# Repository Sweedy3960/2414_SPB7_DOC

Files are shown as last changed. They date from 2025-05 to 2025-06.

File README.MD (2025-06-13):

# 2414_SPB7 – Testeur de Sprinkler

Ce projet implémente un système embarqué pour le test et la gestion de modules Sprinkler, basé sur une architecture modulaire et des tâches gérées par machine à états (FSM), pour microcontrôleur PIC32.

## Sommaire

- [Présentation](#présentation)
- [Fonctionnalités principales](#fonctionnalités-principales)
- [Organisation du projet](#organisation-du-projet)
- [Tableau des fichiers principaux](#tableau-des-fichiers-principaux)
- [Environnement de développement](#environnement-de-développement)
- [Compilation](#compilation)
- [Utilisation](#utilisation)
- [Suivi des tâches](#suivi-des-tâches)
- [Documentation](#documentation)
- [Ressources](#ressources)
- [Notes](#notes)

## Présentation

Ce dépôt contient le code source, la documentation et la configuration pour le projet de testeur de modules Sprinkler.  
L’architecture est orientée événements et intègre la gestion de multiples périphériques (RTC, Touch, ADC, Display, LED, Relais, Buzzer, Bluetooth, SD Card).

## Fonctionnalités principales

- Portage et test de modules (RTC, Touch, ADC, Display, LED, Relais, Buzzer, BT, SD)
- Gestion des tâches via FSM (Harmony)
- Bus d’événements (publish/subscribe)
- Contrôle dynamique des modules (activation, désactivation, flags)
- Gestion des accès I2C/SPI pour éviter les conflits
- Intégration dans la boucle système `SYS_Tasks()`
- Tests de robustesse (non-blocage, endurance SD, consommation)

## Organisation du projet

```
.
├── README.MD
├── doc/
│   ├── ... (documents techniques, schémas, grilles d’évaluation, etc.)
│   ├── EstimPrice/
│   ├── garbage/
│   ├── others/
│   ├── parts/
│   ├── Project Outputs for .../
│   ├── rendus/
├── hard/
│   ├── ... (fichiers hardware, PCB, STEP, etc.)
├── mec/
│   ├── ... (fichiers mécaniques, STEP, DXF, SLDASM, etc.)
├── soft/
│   ├── Chemin.txt
│   ├── Projet.zip
├── tools/
```

## Tableau des fichiers principaux

| Chemin relatif | Description |
|---|---|
| `README.MD` | Présentation et suivi du projet |
| `doc/` | Documentation, rapports, schémas, grilles |
| `doc/EstimPrice/` | Estimations de prix, images de commandes |
| `doc/garbage/` | Archives, idées, schémas à trier |
| `doc/others/` | Notes techniques, calculs, docs annexes |
| `doc/parts/` | Datasheets, notes d’application |
| `doc/Project Outputs for 2414_SAG/` | Sorties CAO, DRC, EuroCircuits, docs design |
| `doc/Project Outputs for 2414_ScreenHolder/` | Idem pour ScreenHolder |
| `doc/Project Outputs for 2414_TesteurDeSprinkler_SPB7/` | Idem pour TesteurDeSprinkler_SPB7 |
| `doc/Project Outputs for 2414_TesteurDeSprinkler_TouchCapa/`| Idem pour TouchCapa |
| `hard/` | Fichiers hardware, PCB, empreintes, etc. |
| `mec/` | Fichiers mécaniques, STEP, DXF, SLDASM |
| `soft/` | Logiciel embarqué, chemins, archives projet |
| `tools/` | Outils divers liés au projet |

## Environnement de développement

- **IDE recommandé** : MPLAB X IDE (Microchip) ou équivalent compatible Harmony
- **Compilateur** : XC32 v2.5 
- **Plateforme cible** : Microcontrôleur PIC32mx79512fl

## Compilation

1. Cloner le repos en local sur la machine 
2. Décompresser le dossier projet dans " C:\microchip\harmony\v2_06\apps\MINF" 
3. Dans Mplab ouvrir le prrojet souhaiter 
4. Vérifier la configuration du compilateur (XC32).
5. Compiler le projet (`Build Project`).
6. Programmer la cible via l’outil de programmation (PICkit, ICD, etc.).

## Utilisation

- Actuellement en développement pas d'utilisation  "normale", le projet flasher est le "SPSPB7_Assembly" 
- Pour l'instant alimenter le prjet en +3V3 sur les fils qui ressortes du boitier 
- une séquence de bienvenus s'affiche, les actions sur les toucbes capacitives on un effet sur les leds et écrans 

- Le  projet "2414-DES_SP7_TestSprinkler" est l'ancienne version du programme de test, il n'est pas utilisable simplement
- il faut l'utiliser en débug et "activer" les fonctionalité à testet grace à des variables globales
- sur cette ancienne version, les fonctionnalité ont été validée jsuqu'a la carte SD 

L'ordre des fonctionalité implémentée: 
- voir rapport

## Taches à venir

- [ ] Repartir sur un projet MPlab vierge et faire la configuration corectement
- [ ] Finir inpmlémenter appInputs -> refractor sm et reconfigurer ADC pour lecture plus rapide 
- [ ] Ajouter la gestion de la tache et crée les fonction de handling
- [ ] Crée la logique pour reporter les entrée sur les sorties 
- [ ] Ajouter l'app MCP /RTC 
- [ ] Ajouter l'app Bluetooth
- [ ] Ajouter l'app Buzzer

## Documentation

La documentation technique (Doxygen, schémas, diagrammes) est disponible dans le dossier du projet:

2414-DES_SP7_TestSprinkler doc : C:\microchip\harmony\v2_06\apps\MINF\Projet\2414-DES_SP7_TestSprinkler\firmware\src\html\index.html"
SPSPB7_Assembly doc: "C:\microchip\harmony\v2_06\apps\MINF\Projet\SPB7_Assembly\firmware\src\html\index.html"

## Ressources

- [MPLAB X IDE](https://www.microchip.com/en-us/tools-resources/develop/mplab-x-ide)
- [Doxygen](https://www.doxygen.nl/index.html)
- [Documentation Microchip PIC32MM](https://www.microchip.com/wwwproducts/en/PIC32MM0064GPL020)
- [VS Code](https://code.visualstudio.com/)
- [Graphviz](https://graphviz.gitlab.io/)

## Notes

- Pour toute modification, mettre à jour ce README et la checklist.
- Les chemins et fichiers peuvent évoluer selon l’avancement du projet.

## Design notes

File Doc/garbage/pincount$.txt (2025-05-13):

pre: 1in 2 out = 3 GPIO
vane: 1in 2 out = 3
test: 1in 2 out = 3
5in:  5 in 10 out = 15
3 in: 3 Ain 3 out = 6
bt: 1in 1 out = 2
buz: 1 out = 1
alarm 1 out = 1
Esser: 24
relais 5 out  = 5 
screen:8 out = 8 
SD:SPI 5 = 6
usb: 2
capa:

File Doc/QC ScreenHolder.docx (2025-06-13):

Dessiné par | ACL | Date dessin | 2025.01.31
Contrôlé par | VCO | Date contrôle | 2025.03.28
N° document | 2414.0000.vo | Nom du projet | SPB7_ScreenHolder

Dessinateur | Contrôleur | Pas applicable | Contrôle | Critères / Remarques

Schéma électrique (SCH)
☒ | ☒ | ☐ | Cartouche | Cartouche complet avec numérotation des pages
☒ | ☒ | ☐ | Repérage | Lettres repères conforme aux normes CEI 81346
☒ | ☒ | ☐ | Symboles | Symboles conformes aux normes CEI 60617
☒ | ☒ | ☐ | Textes | Tous les textes lisibles avec deux sens de lecture
☒ | ☒ | ☐ | Connexions | Fils verticaux ou horizontaux sur une grille de 2.5 mm
☒ | ☒ | ☐ | Exhaustivité | Toutes les connexions nécessaires sont présentes
☒ | ☒ | ☐ | Compilation | Le projet compile sans erreurs

Tracé du circuit imprimé (PCB)
☒ | ☒ | ☐ | Cartouche | Cartouche complet sans numérotation des pages
☒ | ☒ | ☐ | Sérigraphie | Tous les textes lisibles avec deux sens de lecture
☒ | ☒ | ☐ | Graphique / mécanique | Retirer la référence de la sérigraphie
☒ | ☒ | ☐ | Dimensions | Coter le contour mécanique du PCB
☒ | ☒ | ☐ | Découplage | Capacités de découplages au plus près des composants
☒ | ☒ | ☐ | Alimentation | Plans ou topologie en étoile, éviter les boucles, GND et VCCs proches, largeur adaptée
☒ | ☒ | ☐ | Routage | Angles de 45°, largeur appropriées, minimiser les vias, plan de masse sous les composants critiques (ex. quartz)
☒ | ☒ | ☐ | Tables | Table des perçages, numérotation des couches cuivre
☒ | ☒ | ☐ | Règles de conception | Contrôle des règles (DRC) sans erreur

Pochoir (stencil, inclus dans le PCB)
☐ | ☐ | ☒ | Calculs | Calculs des ratios IPC-7525B sur les pastilles critiques, sélection de l’épaisseur du pochoir
☐ | ☐ | ☒ | Réduction | 50 µm ou 10 % ou règle 50/50 pour le fine-pitch
☐ | ☐ | ☒ | Arrondi | Ouvertures arrondies, pas d’angles droits
☐ | ☐ | ☒ | Grandes pastilles | Réduction ou découpage en carrés (50 % surface)

Assemblage (ASY)
☐ | ☐ | ☒ | Cartouche | Cartouche complet avec numérotation des pages
☒ | ☒ | ☐ | Textes | Tous les textes lisibles avec deux sens de lecture
☒ | ☒ | ☐ | Valeurs | La valeur des composants est indiquée sur le dessin

Liste de pièces (BOM)
☒ | ☒ | ☐ | Cartouche | Cartouche complet avec numérotation des pages
☒ | ☒ | ☐ | Contenu | Liste à jour, aux normes ETML, groupée valeur, boîtier

Fichier de placement (PAP)
☐ | ☐ | ☒ | Fichier de placement | Placement à jour, aux normes ETML

Dossier de fabrication (Manufacturing)
☐ | ☐ | ☒ | Dossier Titre_date.zip | Couches format Gerber RS-274X et perçages NC Drill

ETML Liste de contrôle PCB Page 1/2

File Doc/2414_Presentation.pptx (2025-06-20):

## Présentation

Projet : 2414_Testeur de sprinkler

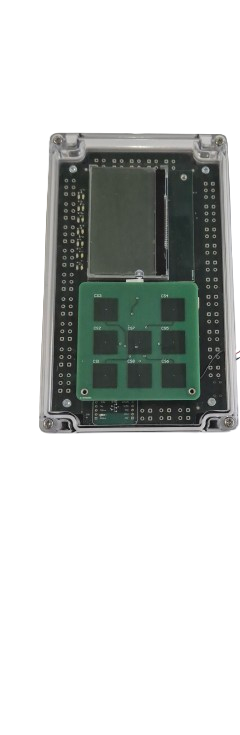
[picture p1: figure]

## Plan de présentation

- 1. Introduction
- 2.Tests et Mesures
- 3. Programmation
- 4. Fait depuis le rendu
- 5. Etat actuel
- 6. Démonstration
- 7. Conclusion

## 1. Introduction

- Contexte du projet:
- Il s’agit de réaliser une évolution d’un boîtier de test pour Sprinkler (détection incendie - DI). Intégration mécanique, densité des composants, fonctionnalités
- I/O extendeur pour Esser 4in/2out
- Le système est censé reporter l’état de certaines entrée sur les sorties en fonction de la configuration initiale affichée l’état et le nom des signaux sur le LCD et utiliser les LEDS pour afficher l’état et faire une sauvegarde

## 2. Test et mesures

- Tests mécaniques et montage du boîtier
- Montage par fonctionnalité progressive
- I/O
- BUS
- Etc

Étapes initiales

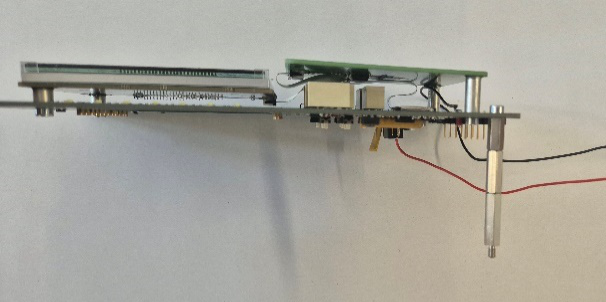
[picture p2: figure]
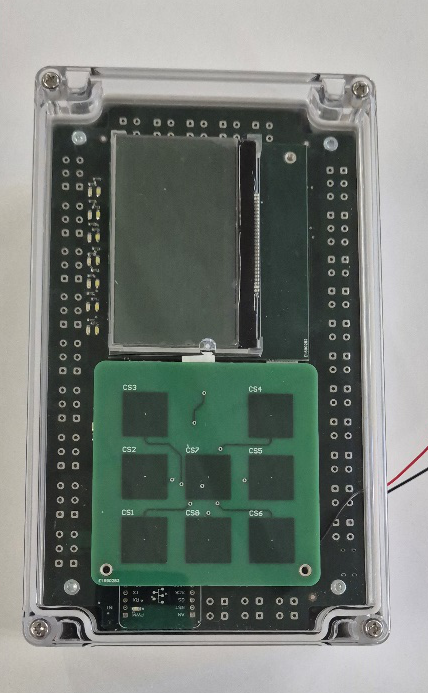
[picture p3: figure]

## 2. Test et mesures - Correction

- Buzzer

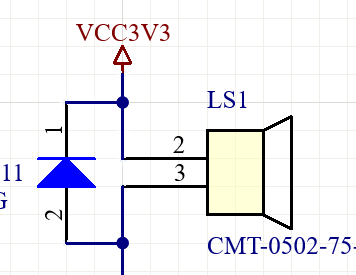
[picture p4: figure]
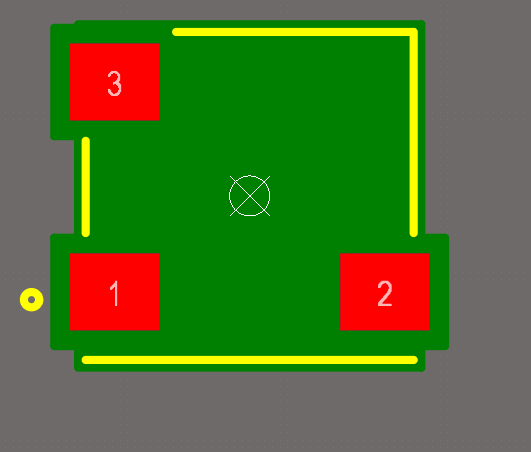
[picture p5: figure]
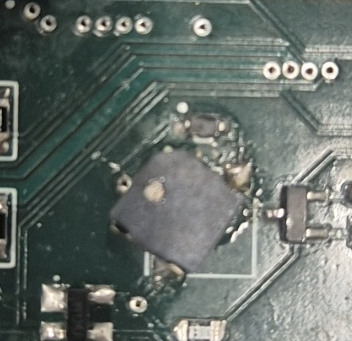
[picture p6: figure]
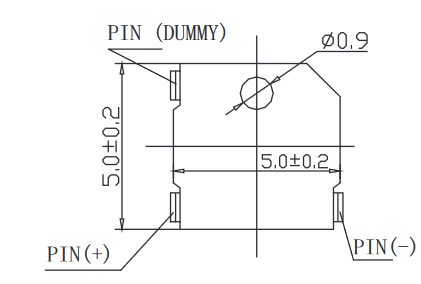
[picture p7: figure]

## 2. Test et mesures - Correction

- Relais

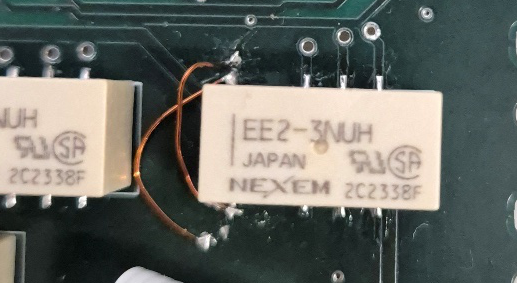
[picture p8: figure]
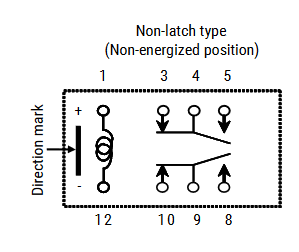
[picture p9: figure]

## 2. Test et mesures - Correction

- Registre à décalage

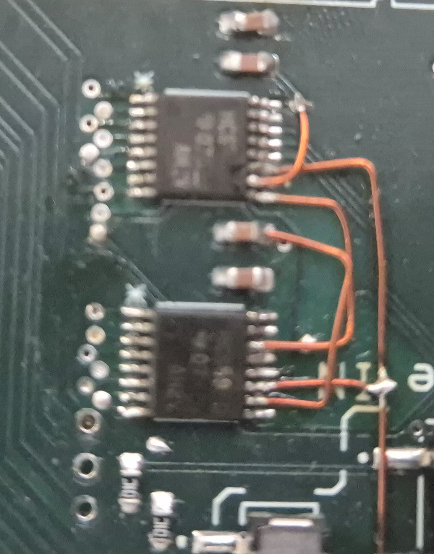
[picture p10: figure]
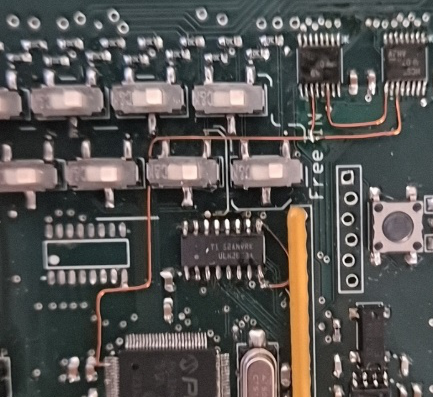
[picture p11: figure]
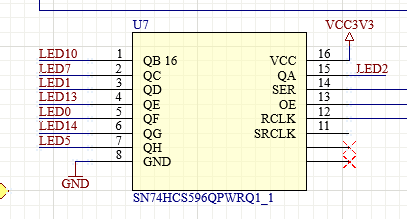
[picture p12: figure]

## 2. Test et mesures - Correction

- Transistor array

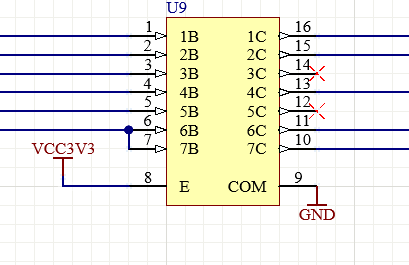
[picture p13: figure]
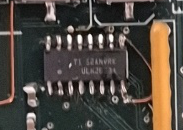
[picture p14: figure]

## 2. Test et mesures - Correction

- SDA/SCL inversés sur TouchCapa

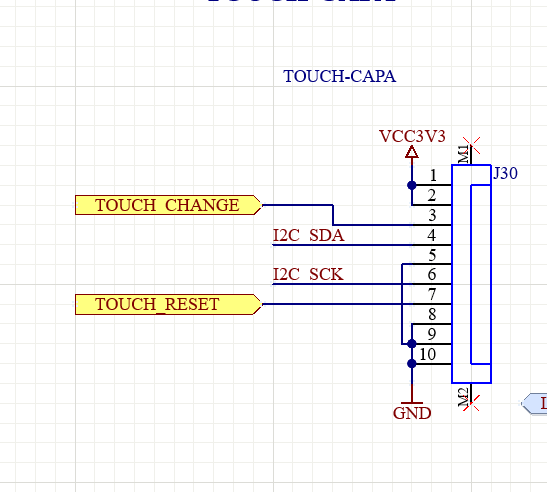
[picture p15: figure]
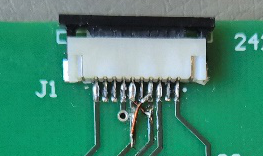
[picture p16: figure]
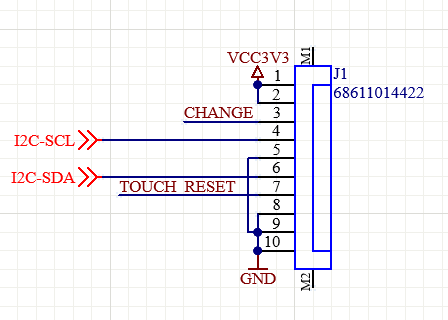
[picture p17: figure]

## 3. Programmation - Fonctionnalités testées

- Entrées digitales et analogiques
- Relais
- RTC
- Touches capacitives
- écran LCD
- Buzzer
- Registre à décalage

## 3. Programmation - Functionalités testées – Problèmes

- Carte SD non détectée (FAT16/FAT32)
- Capacité RTC inefficace à maintenir tension

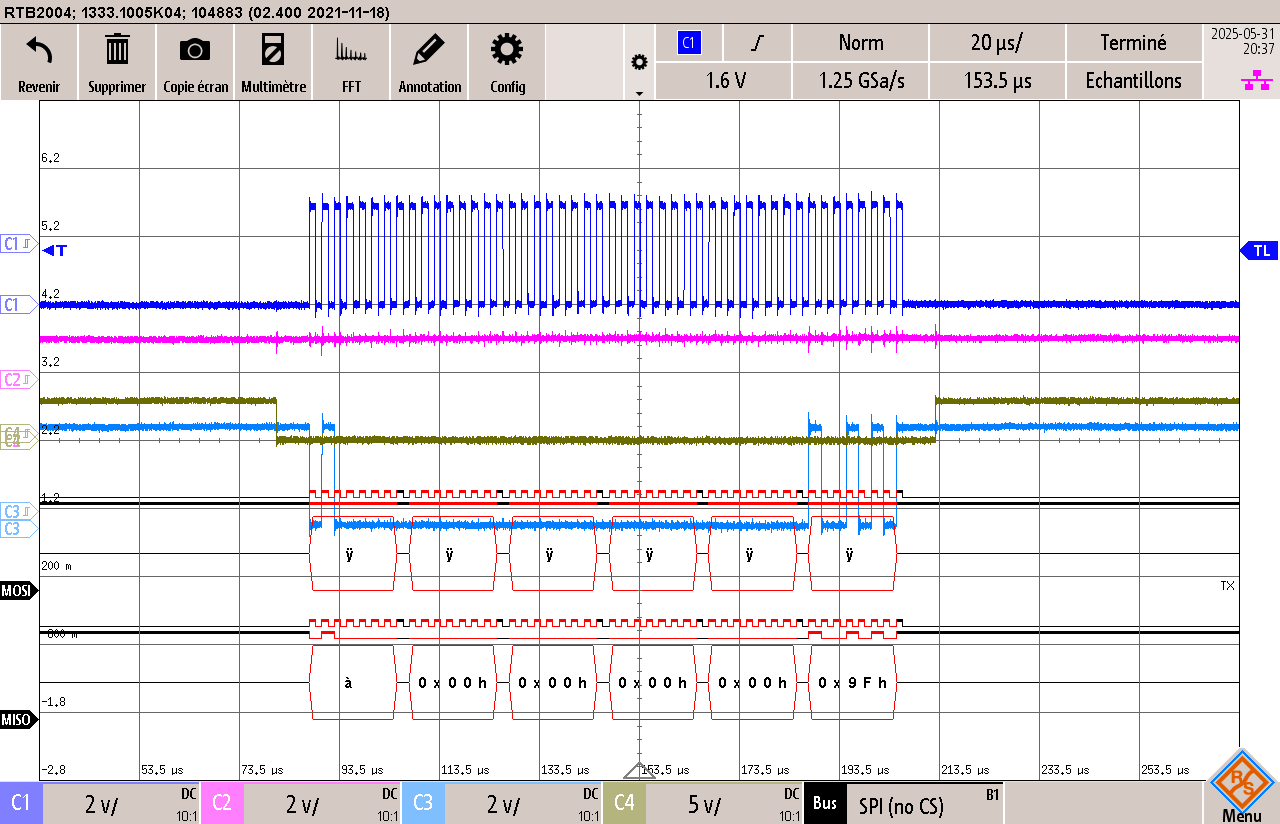
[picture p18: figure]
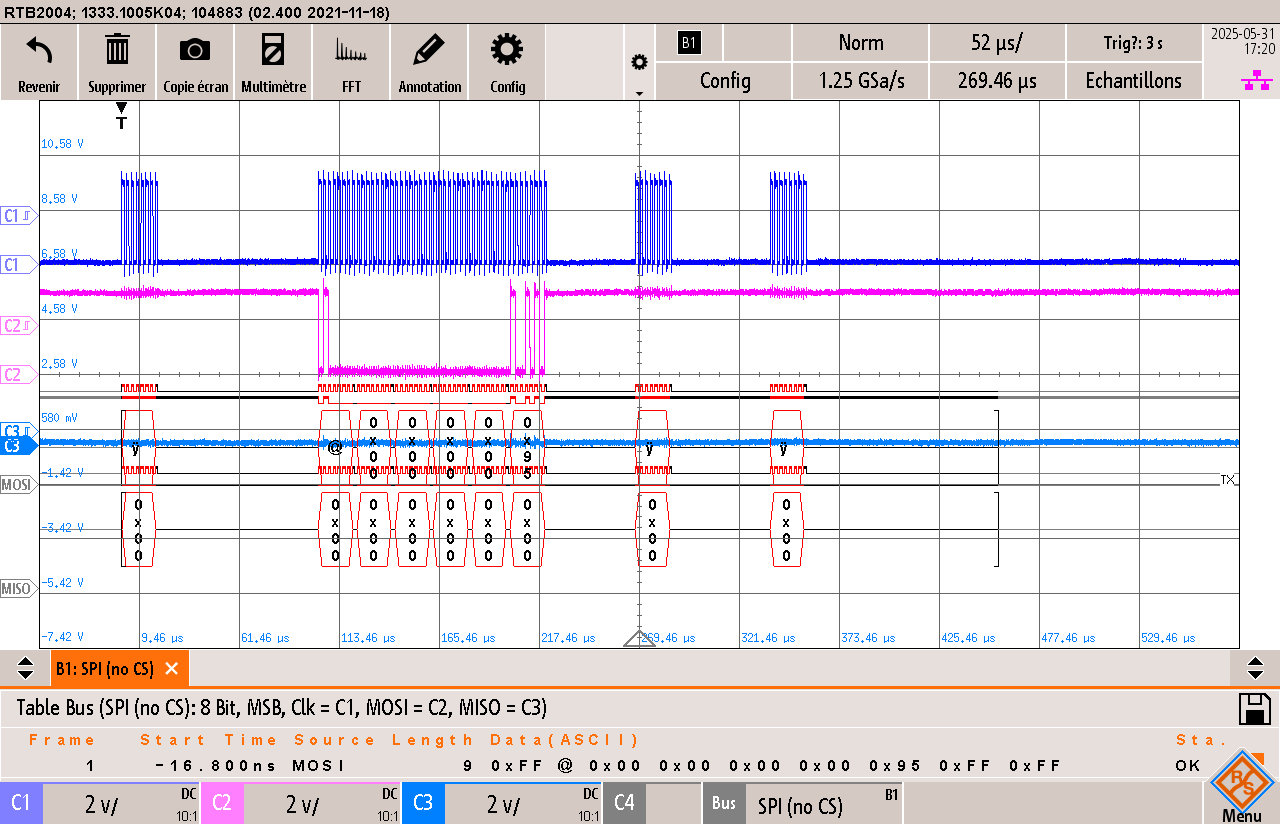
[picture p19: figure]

## 2. Fonctionnalités testées – Tests manquants

- Consommation maximale non mesurée, mais pourquoi ?
- Tests de protection non exécutés → en fin de présentation

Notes: Psk c2c: tout relais ensembles etc

## 2. Problèmes majeurs

- Casse du PCB suite à surtension
- Lecture SD défaillante malgré multiples essais
- USB inutilisable
- Toutes les fonctionnalités ne sont pas intégrées → BT

## 3. Programmation -Développement initial

- Application MPLAB structurée en SM
- Activation des fonctionnalités via variables globales
→ BLOQUE

## 3. Programmation - Méthodologie mergeApp

- Apps dédiées pour chaque fonction et mise en relation via EventBus et TaskControl

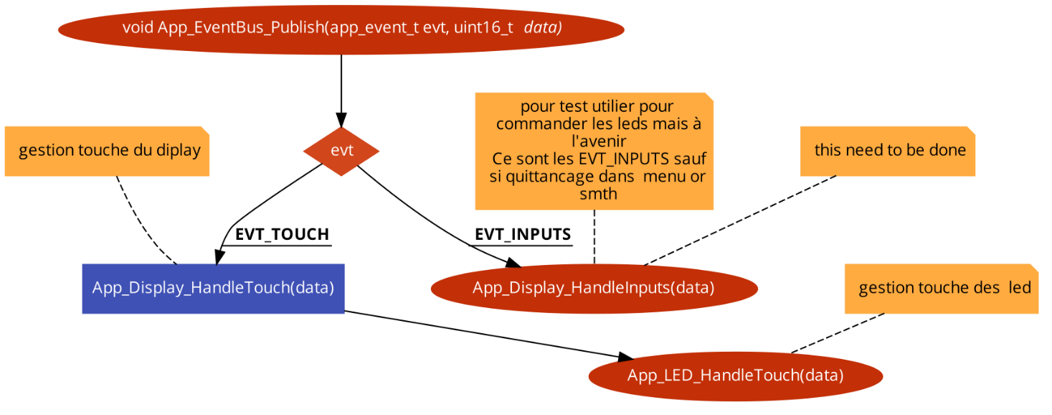
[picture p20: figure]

## 3. Programmation - Limites rencontrées

- Difficulté à maintenir clarté dans l’assemblage
- Structure logicielle à re-repenser ?

## 4. Fait depuis le rendu

- APP au propre dans Harmony
- Ajout fonctionnalité – Inputs
- Test Fonctionnement interruption ligne
- Amélioration du menu
- BOM
- Lien git (nouveau repo): https://github.com/Sweedy3960/SPB7_Test

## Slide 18

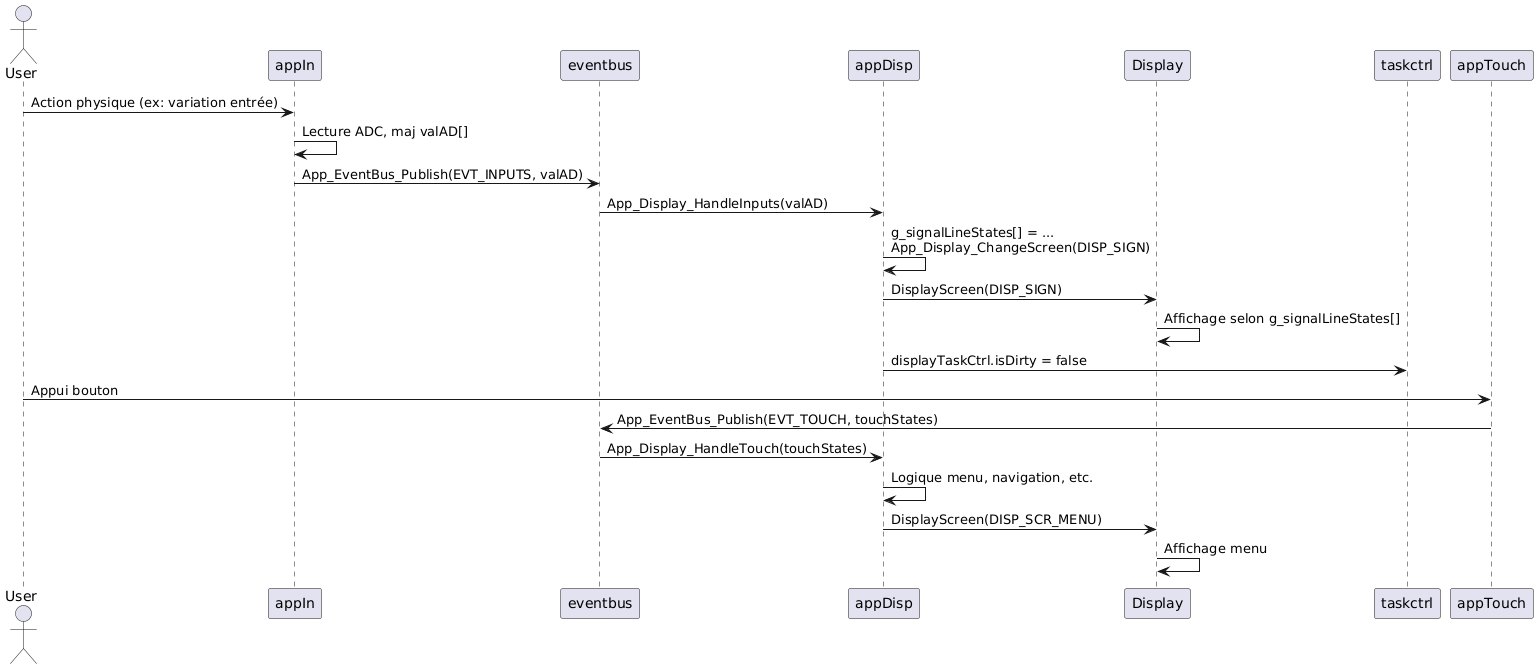
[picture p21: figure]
PlantUML diagram

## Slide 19

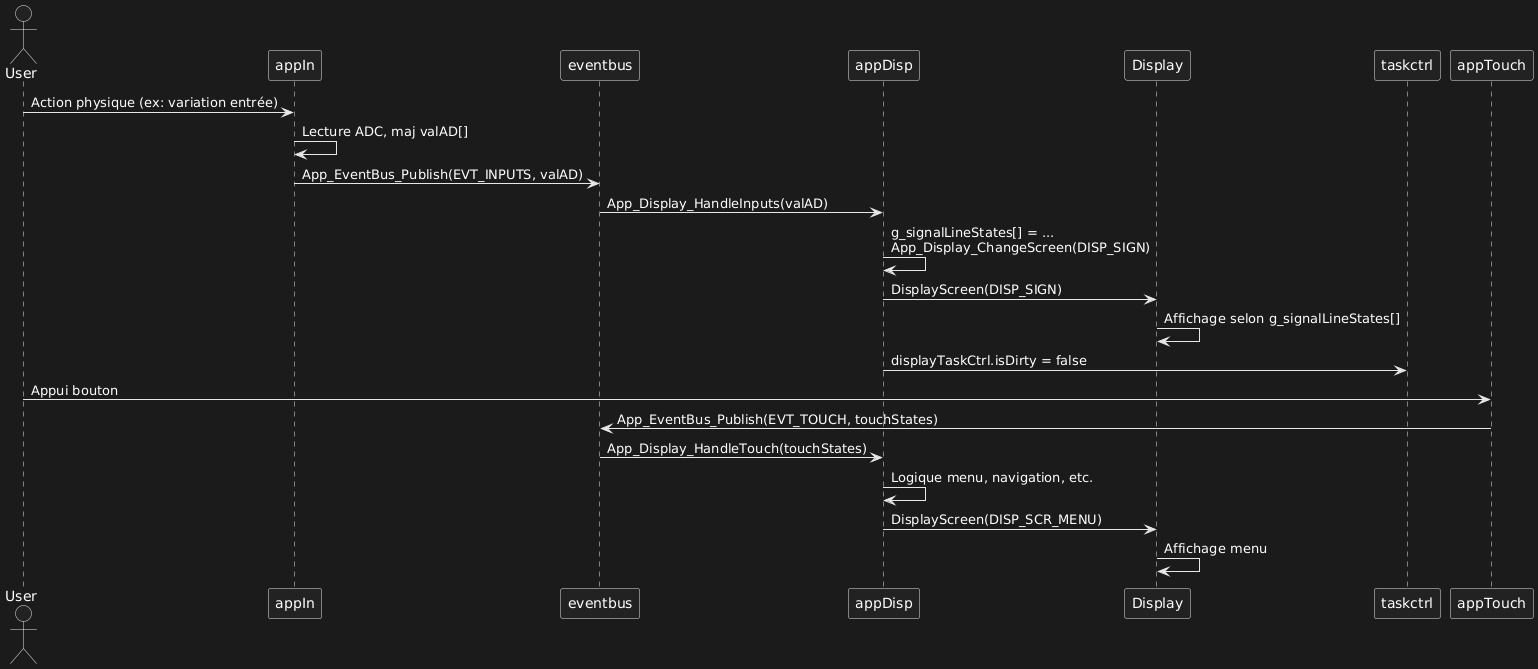
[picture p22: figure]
PlantUML diagram

## 4. Fait depuis le rendu – Comparation des couts

ScreenHolder:

+ Prix des PCB mécanique manquante ~+25% total = 174.78 + 43.7 = ~220CHF

Prévision:
Réel:
SPB7:

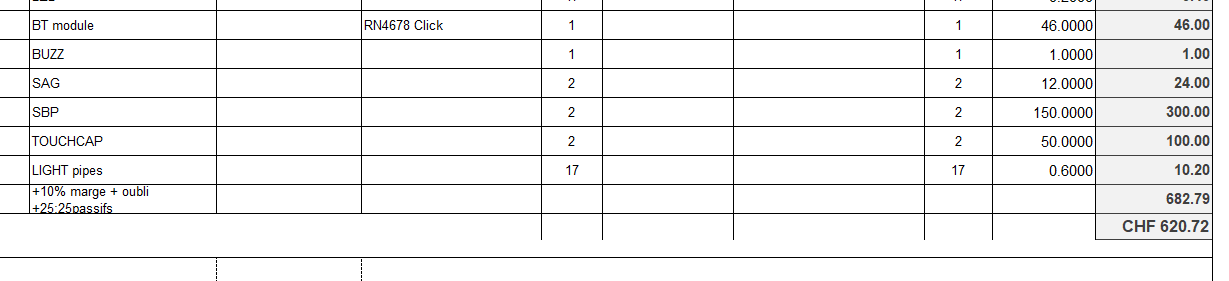
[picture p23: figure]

SAG:

TouchCapa:

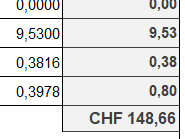
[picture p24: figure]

## 5. Etat actuel -Problèmes

- Montage imprécis hauteur écran / touch
- Alimentation improvisée via trou de test
- Buzzer trop faible
- USB-C inutile pour communication série
- Presse-étoupes absents
- Pas d’adaptation mécanique finale réalisée

## 6. Démo

- Démo

## 6. Conclusion

Bilan du projet:
- Projet incomplet mais riche en apprentissages
- Problèmes techniques variés : hardware, logiciel, méthodologie
Points bloquants persistants:
- Module 4In/2Out toujours non intégré/testé
Doc dispo sur git: https://github.com/Sweedy3960/2414_SPB7_DOC

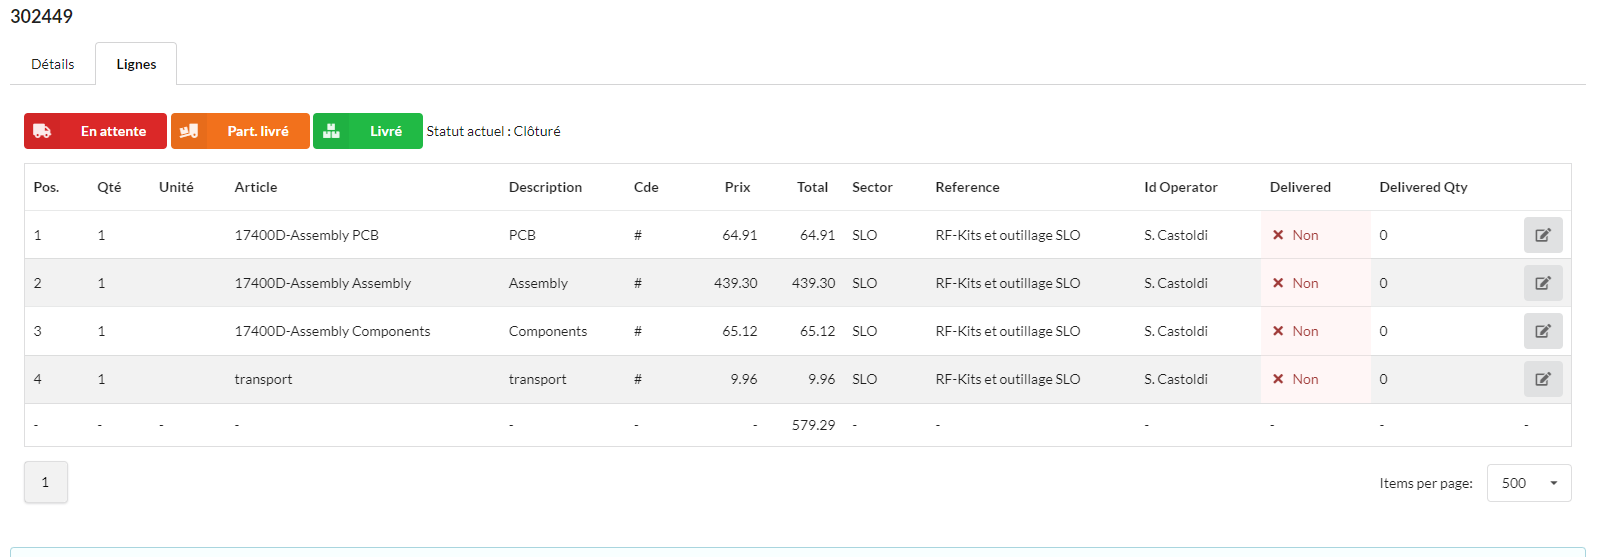
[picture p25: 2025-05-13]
Doc/EstimPrice/CmdKitCasto1_1Pces.png

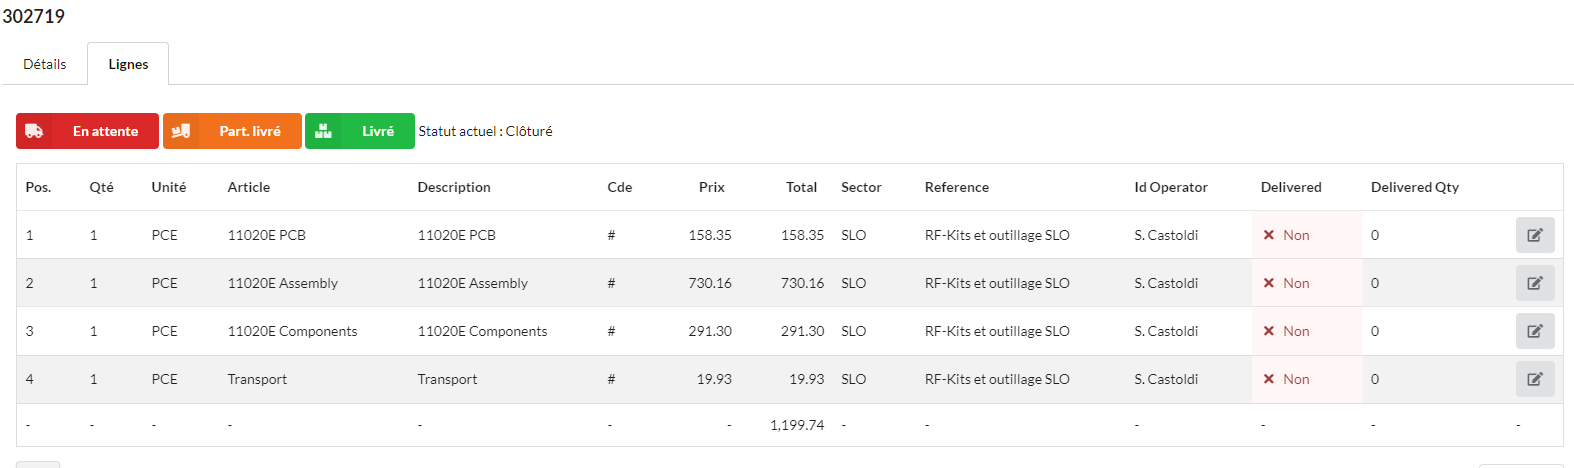
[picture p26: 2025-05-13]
Doc/EstimPrice/CmdKitCasto2_1Pces.png

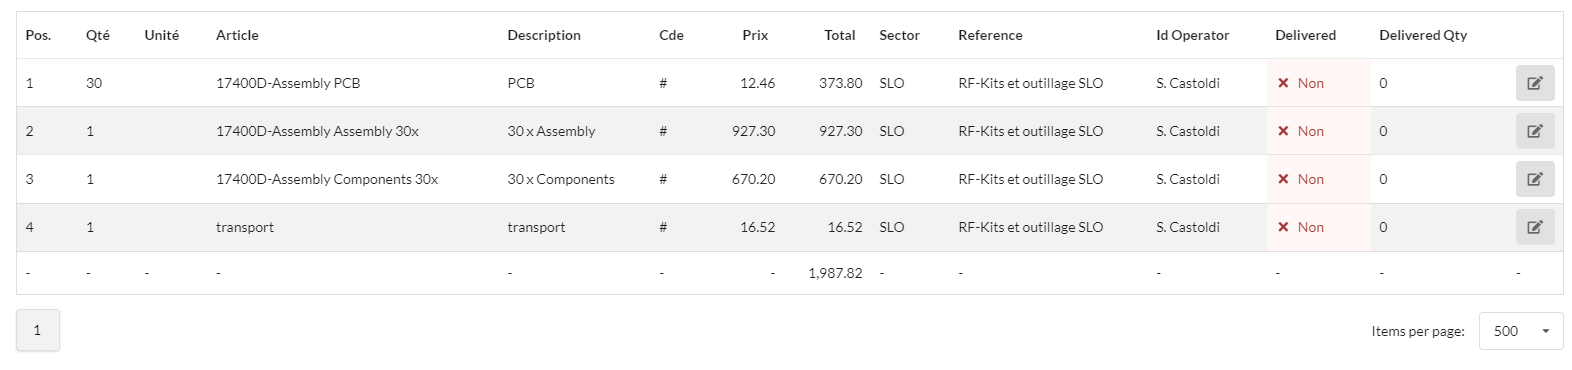
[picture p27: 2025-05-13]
Doc/EstimPrice/CmdKitCasto1_30Pces.png

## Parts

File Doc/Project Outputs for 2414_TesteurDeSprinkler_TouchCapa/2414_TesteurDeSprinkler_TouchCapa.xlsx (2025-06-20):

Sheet: BOM Cost Report
BOM Cost |  | PROJET: | 2414_TesteurDeSprinkler_TouchCapa.PrjPcb |  |  |  |  |  |  | ETML-ES | Rue de Sébeillon 12 1004 Lausanne
Date: | 13.06.2025 | Variante: | None |  |  |  |  |  |  | Quantité de production (nb PCBs) : | 1
Par: | ACL | Source: | 2414_TesteurDeSprinkler_TouchCapa.BomDoc |  |  |  |  |  |  | Devise : | CHF
Line # | Designator | Value | Name | Manufacturer 1 | Manufacturer Part Number 1 | Quantity | Supplier 1 | Supplier Part Number 1 | Supplier Order Qty 1 | Supplier Unit Price 1 | Supplier Subtotal 1
 | C1 | 100nF | 100nF | TDK | CGA3E2X7R1H104K080AA | 1 | Newark | 05X9643 | 1 | 0.0799 | 0.08
 | C2 | 10µF | 10uF | TDK | C1608X5R1A106K080AC | 1 | Mouser | 810-C1608X5R1A106K | 1 | 0.1937 | 0.19
 | C3 | 10nF | 10nF | TDK | C1608X7R1H103K080AA | 1 | Digikey | 445-1311-1-ND | 1 | 0.0807 | 0.08
 | J1 |  | 68611014422 | Wurth Electronics | 68611014422 | 1 | Mouser | 710-68611014422 | 1 | 1.2300 | 1.23
 | MP1, MP2 |  | 9774140360R | Wurth Electronics | 9774140360R | 2 | Farnell | 2438012 | 2 | 1.3400 | 2.67
 | R1 | 68k | 68k | Yageo | RC0603FR-0768KL | 1 | Digikey | 311-68.0KHRCT-ND | 1 | 0.0807 | 0.08
 | R2, R4, R5, R6, R7, R8, R9, R10 | 4.7k | 4k7 | Yageo | RC0603FR-074K7L | 8 | Mouser | 603-RC0603FR-074K7L | 10 | 0.0073 | 0.07
 | R3 | 10k | 10k | Yageo | RC0603FR-0710KL | 1 | Mouser | 603-RC0603FR-0710KL | 1 | 0.0807 | 0.08
 | U1 |  | AT42QT2120-SU | Microchip | AT42QT2120-SU | 1 | Arrow Electronics | AT42QT2120-SU | 1 | 0.3280 | 0.33
 |  |  |  |  |  |  |  |  |  |  | CHF 4.82
Approved | Notes

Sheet: Project Information
Project Full Path | D:\Users\Jose\OneDrive\Documents\3-Engineering\Altium\Projects\PousseAvion\TPA_v2\TPA_v2.PrjPcb
Project Filename | TPA_v2.PrjPcb
Variant Name | None
Data-Source Filename | TPA_v2.PrjPcb
Data-Source Full Path | D:\Users\Jose\OneDrive\Documents\3-Engineering\Altium\Projects\PousseAvion\TPA_v2\TPA_v2.PrjPcb
Title | Batch2-BOM_Digikey for Project [TPA_v2.PrjPcb] (No PCB Document Selected)
Total Quantity | 146
Report Time | 00:02
Report Date | 22.05.2021
Report Date & Tine | 22.05.2021 00:02
Output Name | Batch2-BOM_Digikey
Output Type | BOM_PartType
Output Generator Name | BOM
Output Generator Description | Bill of Materials

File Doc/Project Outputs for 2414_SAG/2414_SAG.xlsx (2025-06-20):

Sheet: BOM Cost Report
BOM Cost |  | PROJET: | 2414_SAG.PrjPcb |  |  |  |  |  |  | ETML-ES | Rue de Sébeillon 12 1004 Lausanne
Date: | 13.06.2025 | Variante: | None |  |  |  |  |  |  | Quantité de production (nb PCBs) : | 1
Par: |  | Source: | 2414_SAG.BomDoc |  |  |  |  |  |  | Devise : | CHF
Line # | Designator | Value | Name | Manufacturer 1 | Manufacturer Part Number 1 | Quantity | Supplier 1 | Supplier Part Number 1 | Supplier Order Qty 1 | Supplier Unit Price 1 | Supplier Subtotal 1
 | J1, J2 |  | 691413720003B | Wurth Electronics | 691413720003B | 2 | Mouser | 710-691413720003B | 2 | 1.0000 | 2.00
 | R1, R2 | 330 | 330R | Yageo | RC0805FR-07330RL | 2 | Newark | 49AK3219 | 2 | 0.0048 | 0.01
 |  |  |  |  |  |  |  |  |  |  | CHF 2.01
Approved | Notes

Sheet: Project Information
Project Full Path | D:\Users\Jose\OneDrive\Documents\3-Engineering\Altium\Projects\PousseAvion\TPA_v2\TPA_v2.PrjPcb
Project Filename | TPA_v2.PrjPcb
Variant Name | None
Data-Source Filename | TPA_v2.PrjPcb
Data-Source Full Path | D:\Users\Jose\OneDrive\Documents\3-Engineering\Altium\Projects\PousseAvion\TPA_v2\TPA_v2.PrjPcb
Title | Batch2-BOM_Digikey for Project [TPA_v2.PrjPcb] (No PCB Document Selected)
Total Quantity | 146
Report Time | 00:02
Report Date | 22.05.2021
Report Date & Tine | 22.05.2021 00:02
Output Name | Batch2-BOM_Digikey
Output Type | BOM_PartType
Output Generator Name | BOM
Output Generator Description | Bill of Materials

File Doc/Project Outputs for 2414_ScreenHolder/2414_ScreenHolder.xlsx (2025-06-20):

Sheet: BOM Cost Report
BOM Cost |  | PROJET: | 2414_ScreenHolder.PrjPcb |  |  |  |  |  |  | ETML-ES | Rue de Sébeillon 12 1004 Lausanne
Date: | 13.06.2025 | Variante: | None |  |  |  |  |  |  | Quantité de production (nb PCBs) : | 1
Par: | ACL | Source: | 2414_ScreenHolder.BomDoc |  |  |  |  |  |  | Devise : | CHF
Line # | Designator | Value | Name | Manufacturer 1 | Manufacturer Part Number 1 | Quantity | Supplier 1 | Supplier Part Number 1 | Supplier Order Qty 1 | Supplier Unit Price 1 | Supplier Subtotal 1
 | C1 | 100nF | 100nF | TDK | CGA3E2X7R1H104K080AA | 1 | Newark | 05X9643 | 1 | 0.0799 | 0.08
 | C2 | 10nF | 10nF | TDK | C1608X7R1H103K080AA | 1 | Digikey | 445-1311-1-ND | 1 | 0.0807 | 0.08
 | C3, C4, C5, C6, C7, C8, C9, C10, C11 | 1µF | 1uF | TDK | C1608X5R1H105K080AB | 9 | Newark | 53W0134 | 10 | 0.0597 | 0.60
 | DS1 |  | NHD-C12864LZ-FSW-FBW-3V3 | Newhaven Display | NHD-C12864LZ-FSW-FBW-3V3 | 1 | Digikey | NHD-C12864LZ-FSW-FBW-3V3-ND | 1 | 14.2400 | 14.24
 | J1 |  | 68611014422 | Wurth Electronics | 68611014422 | 1 | Mouser | 710-68611014422 | 1 | 1.2300 | 1.23
 | MP1, MP2 | M3, Length 5mm | M3, Length 5mm | Wurth Electronics | 9774050360R | 2 | Digikey | 732-5272-1-ND | 2 | 1.4200 | 2.84
 | R1 | 220 | 220R | Yageo | RC0603FR-07220RL | 1 | Newark | 98K7373 | 10 | 0.0073 | 0.07
 | R2 | 3.9 | 3R9 | Yageo | RC0603FR-073R9L | 1 | Digikey | 13-RC0603FR-073R9LCT-ND | 1 | 0.0807 | 0.08
 | R3 | 100k | 100k | Yageo | RC0603FR-07100KL | 1 | Newark | 98K7340 | 10 | 0.0073 | 0.07
 | T1 |  | FDV305N | ON Semiconductor / Fairchild | FDV305N | 1 | Newark | 82C2601 | 1 | 0.0565 | 0.06
 |  |  |  |  |  |  |  |  |  |  | CHF 19.35
Approved | Notes

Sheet: Project Information
Project Full Path | D:\Users\Jose\OneDrive\Documents\3-Engineering\Altium\Projects\PousseAvion\TPA_v2\TPA_v2.PrjPcb
Project Filename | TPA_v2.PrjPcb
Variant Name | None
Data-Source Filename | TPA_v2.PrjPcb
Data-Source Full Path | D:\Users\Jose\OneDrive\Documents\3-Engineering\Altium\Projects\PousseAvion\TPA_v2\TPA_v2.PrjPcb
Title | Batch2-BOM_Digikey for Project [TPA_v2.PrjPcb] (No PCB Document Selected)
Total Quantity | 146
Report Time | 00:02
Report Date | 22.05.2021
Report Date & Tine | 22.05.2021 00:02
Output Name | Batch2-BOM_Digikey
Output Type | BOM_PartType
Output Generator Name | BOM
Output Generator Description | Bill of Materials

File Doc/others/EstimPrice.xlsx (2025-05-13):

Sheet: BOM Cost Report
BOM Cost |  | PROJET: | 2414-DES_SPB_7_TestSprinkler ESTIMATION |  |  |  |  |  |  | ETML-ES | Rue de Sébeillon 12 1004 Lausanne
Date: | 2024-12-01 | Variante: |  |  |  |  |  |  |  | Quantité de production (nb PCBs) : | 1
Par: |  | Source: | 2414-DES_SPB_7_TestSprinkler |  |  |  |  |  |  | Devise : | CHF
Line # | Designator | #Column Name Error:' Value | Name | Manufacturer 1 | Manufacturer Part Number 1 | Quantity | Supplier 1 | Supplier Part Number 1 | Supplier Order Qty 1 | Supplier Unit Price 1 | Supplier Subtotal 1
 | GRAPHIC DISPLAY FSTN BLACK (WHIT |  | NHD-C12864LZ-FSW-FBW-3V3 | Newhaven Display Intl | NHD-C12864LZ-FSW-FBW-3V3 | 1 |  |  | 1 | 17.7 | 17.70
 |  |  | SD connect |  | 1051620001 | 1 |  |  | 1 | 0.35 | 0.35
 |  |  | bornier cable plat |  | 68611014422 | 2 |  |  | 2 | 1.2 | 2.40
 |  |  | switch config |  | SLW-913535-2A-SMT | 9 |  |  | 9 | 0.55 | 4.95
 |  |  | TVS |  | GSOT04C-E3-08 | ~30 |  |  | 30 | 0.3 | 9.00
 |  |  | boitier |  | PN-1334-C | 1 |  |  | 1 | 22.35 | 22.35
 |  |  | 5.00 MM TERMINAL BLOCK, 45 ENTR |  | 691413720006B | ~30 |  |  | 30 | 2.06 | 61.80
 |  |  | relais |  | J104D2C3VDC.20S | 6 |  |  | 6 | 1.23
 |  |  | relais secours |  | UD2-3NU | 6 |  |  | 6 | 1.57 | 9.42
 |  |  | touch capa interfacer |  | AT42QT2120-SU | 1 |  |  | 1 | 1.45 | 1.45
 | EXAMPLE |  | MOS |  | PMV160UP,215 | ~10 |  |  | 10 | 0.4 | 4.00
 |  |  | rtc |  | MCP79411-I/SN | 1 |  |  | 1 | 1.0000 | 1.00
 | EXAMPLE |  | zener/diode |  |  | ~30 |  |  | 30 | 0.5000 | 15.00
 | EXAMPLE |  | buck |  | MAX17554AATA+ | 2 |  |  | 2 | 2.2000 | 4.40
 |  |  | LED |  |  | 17 |  |  | 17 | 0.2000 | 3.40
 |  |  | BT module |  | RN4678 Click | 1 |  |  | 1 | 46.0000 | 46.00
 |  |  | BUZZ |  |  | 1 |  |  | 1 | 1.0000 | 1.00
 | PCB |  | SAG |  |  | 2 |  |  | 2 | 12.0000 | 24.00
 | PCB |  | SBP |  |  | 2 |  |  | 2 | 150.0000 | 300.00
 | PCB |  | TOUCHCAP |  |  | 2 |  |  | 2 | 50.0000 | 100.00
 |  |  | LIGHT pipes |  |  | 17 |  |  | 17 | 0.6000 | 10.20
 |  |  | +10% marge + oubli +25:25passifs |  |  |  |  |  |  |  | 682.79
 |  |  |  |  |  |  |  |  |  |  | CHF 620.72
Approved | Notes

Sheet: Project Information
Project Full Path | D:\Users\Jose\OneDrive\Documents\3-Engineering\Altium\Projects\PousseAvion\TPA_v2\TPA_v2.PrjPcb
Project Filename | TPA_v2.PrjPcb
Variant Name | None
Data-Source Filename | TPA_v2.PrjPcb
Data-Source Full Path | D:\Users\Jose\OneDrive\Documents\3-Engineering\Altium\Projects\PousseAvion\TPA_v2\TPA_v2.PrjPcb
Title | Batch2-BOM_Digikey for Project [TPA_v2.PrjPcb] (No PCB Document Selected)
Total Quantity | 146
Report Time | 00:02
Report Date | 22.05.2021
Report Date & Tine | 22.05.2021 00:02
Output Name | Batch2-BOM_Digikey
Output Type | BOM_PartType
Output Generator Name | BOM
Output Generator Description | Bill of Materials

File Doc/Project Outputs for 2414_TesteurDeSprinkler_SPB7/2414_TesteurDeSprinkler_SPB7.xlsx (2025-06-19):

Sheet: BOM Cost Report
BOM Cost |  | PROJET: | 2414_TesteurDeSprinkler_SPB7.PrjPcb |  |  |  |  |  |  | ETML-ES | Rue de Sébeillon 12 1004 Lausanne
Date: | 13.06.2025 | Variante: | None |  |  |  |  |  |  | Quantité de production (nb PCBs) : | 1
Par: |  | Source: | 2414_TesteurDeSprinkler_SPB7.BomDoc |  |  |  |  |  |  | Devise : | CHF
Line # | Designator | Value | Name | Manufacturer 1 | Manufacturer Part Number 1 | Quantity | Supplier 1 | Supplier Part Number 1 | Supplier Order Qty 1 | Supplier Unit Price 1 | Supplier Subtotal 1
 | R2 | 1k | 1k0 | Yageo | RC0805FR-071KL | 1 | Newark | 82K7536 | 1 | 0.0032 | 0.00325
 | R30 | 1.5k | 1k5 | Yageo | RC0603FR-071K5L | 1 | Newark | 98K7356 | 10 | 0.0081 | 0.08
 | C15, C17, C25, C31 | 1µF | 1uF | TDK | C1608X5R1H105K080AB | 4 | Mouser | 810-C1608X5R1H105K | 4 | 0.1218 | 0.49
 | R27, R28 | 2.2k | 2k2 | Yageo | RC0603FR-072K2L | 2 | Mouser | 603-RC0603FR-072K2L | 10 | 0.0089 | 0.09
 | C29, C36 | 4.7µF | 4.7uF | TDK | C1608X5R1C475K080AC | 2 | Mouser | 810-C1608X5R1C475KAC | 2 | 0.1705 | 0.34
 | R3, R29, R35, R36, R37, R38, R39, R40, R41, R42, R43, R44, R45, R46, R47, R48, R49, R50 | 10k | 10k | Yageo | RC0603FR-0710KL | 18 | Mouser | 603-RC0603FR-0710KL | 18 | 0.0073 | 0.13
 | R1, R31, R32, R59, R60, R61, R62, R63, R64, R66, R67, R68 | 10k | 10k | Yageo | RC0805FR-0710KL | 12 | Mouser | 603-RC0805FR-0710KL | 12 | 0.0130 | 0.16
 | C14, C16, C32 | 10nF | 10nF | TDK | C1608X7R1H103K080AA | 3 | Digikey | 445-1311-1-ND | 3 | 0.0812 | 0.24
 | C30 | 10pF | 10pF | Walsin Technologies | 0603N100J500CT | 1 | Digikey | 1292-1471-1-ND | 1 | 0.0812 | 0.08
 | C3, C26 | 10µF | 10uF | TDK | C1608X5R1A106K080AC | 2 | Mouser | 810-C1608X5R1A106K | 2 | 0.1948 | 0.39
 | C1, C2 | 22pF | 22pF | TDK | C1608C0G1H220J080AA | 2 | Mouser | 810-C1608C0G1H220J | 2 | 0.0812 | 0.16
 | R11 | 22 | 22R | Yageo | RC0603FR-0722RL | 1 | Newark | 26M6754 | 10 | 0.0073 | 0.07
 | R33, R34 | 27 | 27R | Yageo | RC0805FR-0727RL | 2 | Newark | 49AK3169 | 2 | 0.0049 | 0.01
 | C33, C34 | 47pF | 47pF | TDK | C1608C0G1H470J080AA | 2 | Newark | 55T0097 | 2 | 0.0057 | 0.01
 | C4, C5, C6, C8, C9, C10, C11, C12, C27, C35, C37 | 100nF | 100nF | TDK | CGA3E2X7R1H104K080AA | 11 | Mouser | 810-CGA3E2X7R1H104K | 11 | 0.0357 | 0.39
 | C7 |  | 100nF | TDK | CGA3E2X7R1H104K080AA | 1 | Distrelec | 30180406 | 1 | 0.0500 | 0.05
 | C28 | 100pF | 100pF | TDK | CGA3E2C0G1H101J080AA | 1 | Newark | 80X3162 | 1 | 0.0106 | 0.01
 | R26 | 100 | 100R | Yageo | RC0603FR-07100RL | 1 | Newark | 98K7334 | 10 | 0.0081 | 0.08
 | R8 | 220 | 220R | Yageo | RC0603FR-07220RL | 1 | Newark | 98K7373 | 10 | 0.0073 | 0.07
 | R7, R9, R10, R12, R13, R14, R15, R16, R17, R18, R19, R20, R21, R23, R24, R25 | 270 | 270R | Yageo | RC0603FR-07270RL | 16 | Newark | 98K7385 | 16 | 0.0016 | 0.03
 | R51, R52, R53, R54, R56, R57, R58, R65, R73, R74, R75, R76, R77 | 330 | 330R | Yageo | RC0603FR-07330RL | 13 | Newark | 98K7391 | 13 | 0.0073 | 0.09
 | R5, R6, R22 | 470 | 470R | Yageo | RC0805FR-07470RL | 3 | Digikey | 311-470CRCT-ND | 10 | 0.0097 | 0.10
 | RN1 |  | 4610X-101-103LF | Bourns | 4610X-101-103LF | 1 | Newark | 62J2940 | 1 | 0.1161 | 0.12
 | R70 |  | 100000Ohm, 250mW | Panasonic | ERJ-S08F66R5V | 1 | Digikey | ERJ-S08F66R5V-ND | 1 | 0.1705 | 0.17
 | D1, D2, D3, D4, D5, D6, D7, D8, D28 |  | 8240136 | Wurth Electronics | 8240136 | 9 | Mouser | 710-8240136 | 9 | 1.0400 | 9.35
 | J15, J30 |  | 68611014422 | Wurth Electronics | 68611014422 | 2 | Mouser | 710-68611014422 | 2 | 1.2400 | 2.48
 | S1 |  | 430182043816 | Wurth Electronics | 430182043816 | 1 | Digikey | 732-7004-1-ND | 1 | 0.4303 | 0.43
 | J1, J2, J3, J4, J5, J6, J7, J8, J9, J10, J11, J13, J14, J21, J22, J25, J26 |  | 691413720002B | Wurth Electronics | 691413720002B | 17 | Digikey | 732-691413720002B-ND | 17 | 0.5748 | 9.77
 | J12, J27, J28_Rel_Ch1, J28_Rel_Ch2, J28_Rel_Ch3, J28_Rel_Ch4, J28_Rel_Ch5, J28_Rel_Ch6, J28_Rel_Ch7, J28_Rel_Ch8, J31 |  | 691413720003B | Wurth Electronics | 691413720003B | 11 | Digikey | 732-691413720003B-ND | 11 | 0.9621 | 10.58
 | J16 |  | 693072010801 | Wurth Electronics | 693072010801 | 1 | Digikey | 732-3820-1-ND | 1 | 2.7700 | 2.77
 | Q3 | ATS080BSM-1 | ATS080BSM-1 | CTS | ATS080BSM-1 | 1 | Mouser | 774-ATS080BSM-1 | 1 | 0.4140 | 0.41
 | D11 |  | BAT54HT1G | ON Semiconductor / Fairchild | BAT54HT1G | 1 | Newark | 83H6419 | 1 | 0.0341 | 0.03
 | LS1 |  | CMT-0502-75-SMT-TR | Same Sky | CMT-0502-75-SMT-TR | 1 | Mouser | 490-CMT-0502-75SMTTR | 1 | 1.5700 | 1.57
 | K1, K2_Rel_Ch1, K2_Rel_Ch2, K2_Rel_Ch3, K2_Rel_Ch4, K2_Rel_Ch5, K2_Rel_Ch6, K2_Rel_Ch7, K2_Rel_Ch8 |  | EE2-3NUH-L | KEMET | EE2-3NUH-L | 9 | Mouser | 80-EE2-3NUH-L | 9 | 2.0400 | 18.34
 | C13 |  | EEEFK1H220P | Panasonic | EEE-FK1H220P | 1 | Newark | 85AK4230 | 1 | 0.0812 | 0.08
 | T2 |  | FDV305N | ON Semiconductor / Fairchild | FDV305N | 1 | Mouser | 512-FDV305N | 1 | 0.3491 | 0.35
 | U4 | FT230XS | FT230XS | FTDI | FT230XS-R | 1 | Newark | 83T7087 | 1 | 1.7800 | 1.78
 | Q1 |  | IRF4905 | Infineon | IRF4905PBF | 1 | Newark | 63J7300 | 1 | 0.8606 | 0.86
 | SW1, SW2, SW3, SW4, SW5, SW6, SW7, SW8, SW9, SW10, SW11 |  | JS102011SCQN | ITT C&K | JS102011SCQN | 11 | Digikey | CKN10877CT-ND | 10 | 0.8700 | 7.36
 | D26 |  | LED_B | QT-Brightek | QBLP631-2IB5 | 1 | Digikey | 1516-QBLP631-2IB5CT-ND | 1 | 0.2505 | 0.25
 | D23 |  | LED_G | QT-Brightek | QBLP631-YG15 | 1 | Digikey | 1516-QBLP631-YG15CT-ND | 1 | 0.2436 | 0.24
 | D24 |  | LED_R | QT-Brightek | QBLP631-R5-2897 | 1 | Digikey | 1516-QBLP631-R5-2897CT-ND | 1 | 0.1786 | 0.18
 | D12, D14, D16, D18, D20, D25, D27 |  | LED_W | Inolux | IN-S85AT5UW | 7 | Digikey | 1830-1080-1-ND | 10 | 0.1218 | 1.22
 | D10, D13, D15, D17, D19, D21, D22 |  | LED_Y | QT-Brightek | QBLP631-Y5-2897 | 7 | Digikey | 1516-QBLP631-Y5-2897CT-ND | 10 | 0.1721 | 1.72
 | D9 |  | LYR976 | QT Brightek | QBLP631-Y5-2897 | 1 | Digikey | 1516-QBLP631-Y5-2897CT-ND | 1 | 0.2517 | 0.25
 | MP1, MP2, MP3, MP4 | M3, Length 5mm | M3, Length 5mm | Wurth Electronics | 9774020360R | 4 | Newark | 22AC5236 | 4 | 0.4839 | 1.94
 | Q2 | MC-306 32.7680K-A3: ROHS | MC-306 32.7680K-A3: ROHS | Epson | MC-30632.7680K-A3:ROHS | 1 | Digikey | SER4306CT-ND | 1 | 2.1600 | 2.16
 | U3 |  | MCP79411 | Microchip | MCP79411-I/MS | 1 | Heisener | MCP79411-I/MS | 1 | 0.8821 | 0.88
 | U1 |  | MIKROBUS HOST CONN. | mikroElektronika | MIKROE-4677 | 1 | Mouser | 932-MIKROE-4677 | 1 | 35.7200 | 35.72
 | U2 |  | PIC32MX795F512L | Microchip | PIC32MX795F512L-80I/PT | 1 | Newark | 53R2068 | 1 | 3.2600 | 3.26
 | P1 | Pin List 1x2 | Pin List 1x2 |  |  | 1 | N.A. | N.A.
 | MD1 |  | RN4678-V/RM111 | Microchip | RN4678-V/RM111 | 1 | Mouser | 579-RN4678-V/RM111 | 1 | 10.7100 | 10.70
 | F1 |  | RUEF250 | Littelfuse | RUEF250 | 1 | Mouser | 650-RUEF250 | 1 | 0.3653 | 0.37
 | X1, X2, X3, X4, X5, X6, X7, X8, X9, X10, X11, X12, X13, X14, X15, X16, X17, X18, X19, X20, X21, X22, X23, X24 |  | S9141-45R | Harwin | S9141-45R | 24 | Mouser | 855-S9141-45R | 24 | 0.3556 | 8.53
 | U6, U7 |  | SN74HCS596QPWRQ1_1 | Texas Instruments | SN74HCS596QPWRQ1 | 2 | Digikey | 296-SN74HCS596QPWRQ1CT-ND | 2 | 0.4952 | 0.99
 | P2 |  | Tac_Contact_Prog |  |  | 1 |  |  |  | 0.0000 | 0.00
 | U5 |  | TSR 2-2433 | Traco Power | TSR2-2433 | 1 | Mouser | 495-TSR2-2433 | 1 | 9.5300 | 9.53
 | J29 |  | UJC-HP2-3-SMT-TR | Same Sky | UJC-HP2-3-SMT-TR | 1 | Mouser | 179-UJC-HP2-3-SMT-TR | 1 | 0.3816 | 0.38
 | U8, U9 |  | ULN2003ADR | Texas Instruments | ULN2003ADR | 2 | Mouser | 595-ULN2003ADR | 2 | 0.3978 | 0.80
 |  |  |  |  |  |  |  |  |  |  | CHF 148.66
Approved | Notes

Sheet: Project Information
Project Full Path | D:\Users\Jose\OneDrive\Documents\3-Engineering\Altium\Projects\PousseAvion\TPA_v2\TPA_v2.PrjPcb
Project Filename | TPA_v2.PrjPcb
Variant Name | None
Data-Source Filename | TPA_v2.PrjPcb
Data-Source Full Path | D:\Users\Jose\OneDrive\Documents\3-Engineering\Altium\Projects\PousseAvion\TPA_v2\TPA_v2.PrjPcb
Title | Batch2-BOM_Digikey for Project [TPA_v2.PrjPcb] (No PCB Document Selected)
Total Quantity | 146
Report Time | 00:02
Report Date | 22.05.2021
Report Date & Tine | 22.05.2021 00:02
Output Name | Batch2-BOM_Digikey
Output Type | BOM_PartType
Output Generator Name | BOM
Output Generator Description | Bill of Materials

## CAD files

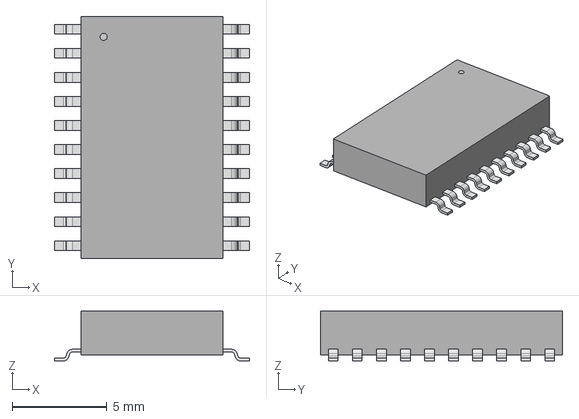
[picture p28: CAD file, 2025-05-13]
hard/Footprint/AT42QT2120_SU/AltiumDesigner/SOIC20-W_MC_MCH.step
10.3 x 12.8 x 2.64 mm

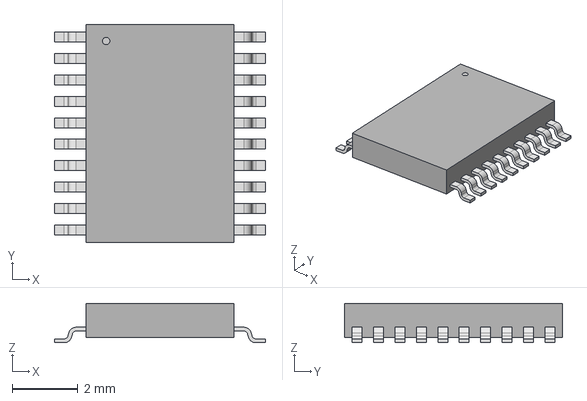
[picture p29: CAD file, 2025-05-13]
hard/Footprint/AT42QT2120_XUR/AltiumDesigner/TSSOP20_MC_MCH.step
6.40 x 6.60 x 1.20 mm

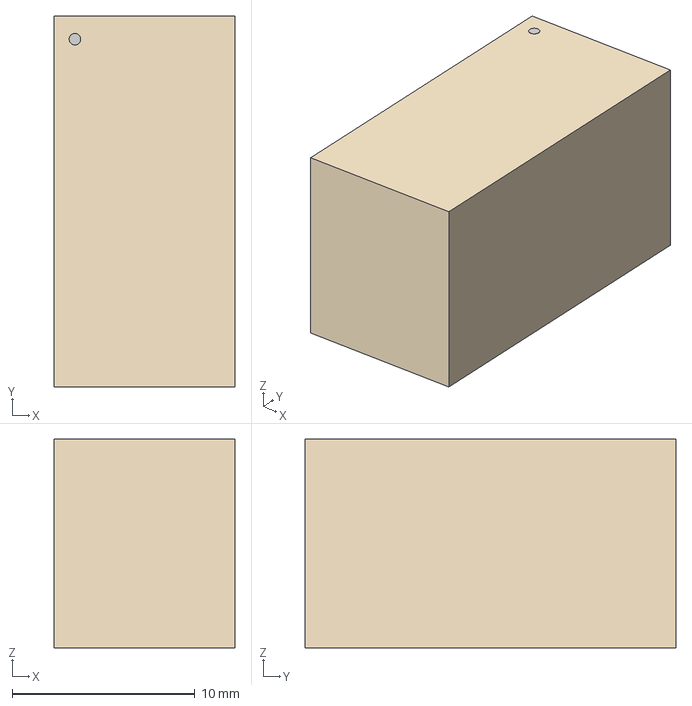
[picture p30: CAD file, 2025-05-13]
hard/Footprint/J104D2C3VDC_20S/AltiumDesigner/RELAY_J104D2C3VDC20S_CRS.step
9.91 x 20.3 x 11.4 mm

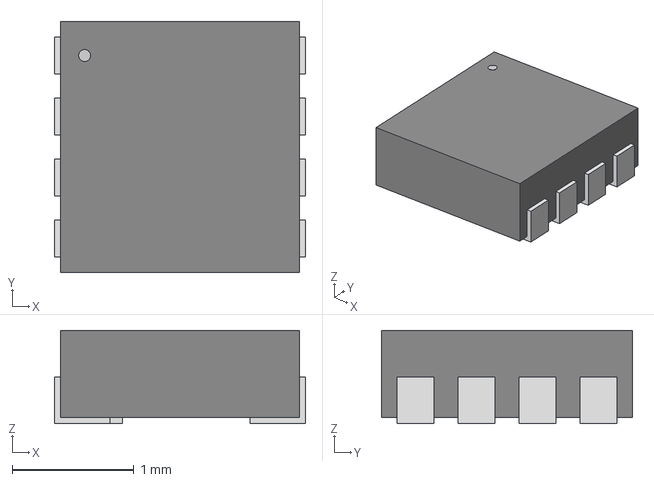
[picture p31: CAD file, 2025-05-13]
hard/Footprint/MAX17554AATA_/21-0487_T822CN1_ADI.step
2.06 x 2.06 x 0.765 mm

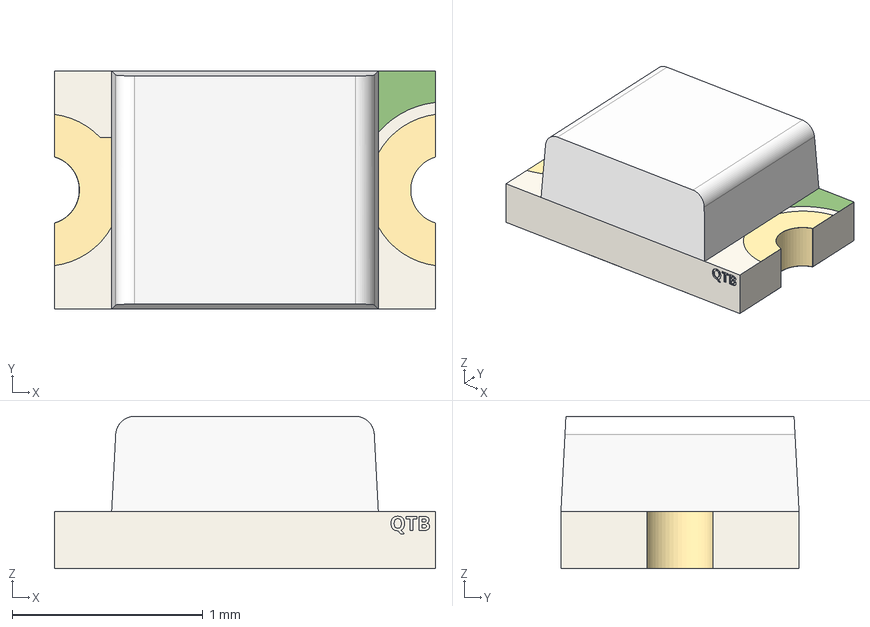
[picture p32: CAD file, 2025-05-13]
hard/Footprint/QBLP631_MONO/QBLP631_MONO.step
2.00 x 1.25 x 0.8 mm
Resin
Polarity Mark
Bottom Pad 2
Bottom Pad 1
Bottom Pad - Mid

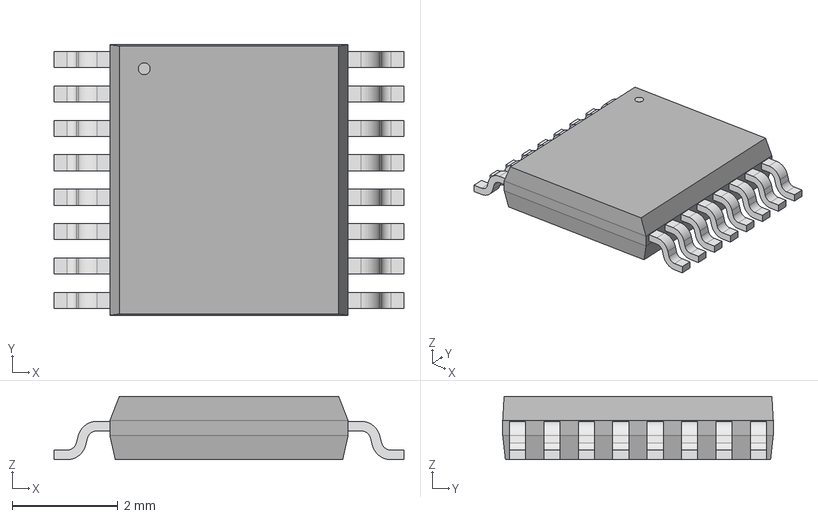
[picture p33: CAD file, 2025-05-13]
hard/Footprint/SN74HCS596QPWRQ1/AltiumDesigner/TSSOP_QPWRQ1_TEX.step
6.60 x 5.11 x 1.20 mm

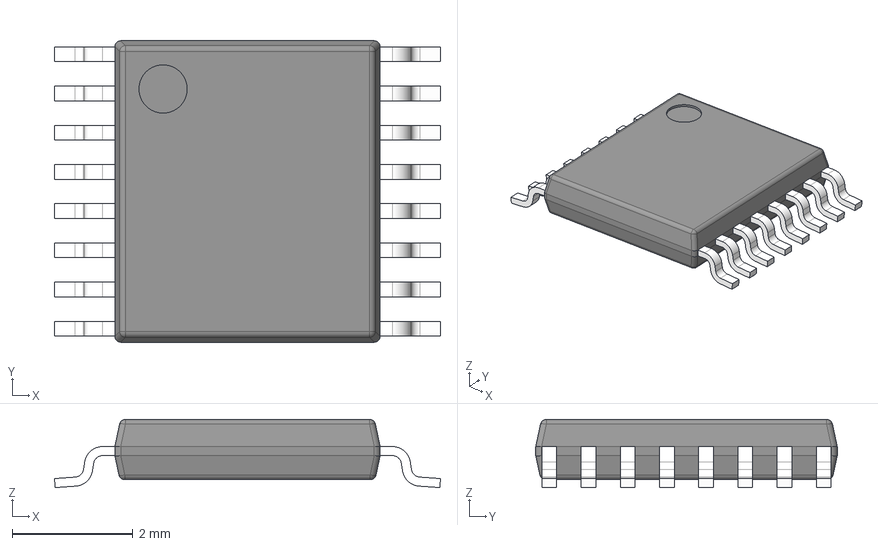
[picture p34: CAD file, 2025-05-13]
hard/Footprint/SN74HCS596QPWRQ1/PW0016A.stp
6.40 x 5.00 x 1.13 mm
BODY-TSSOP
LEAD-TSSOP x 16
PIN1

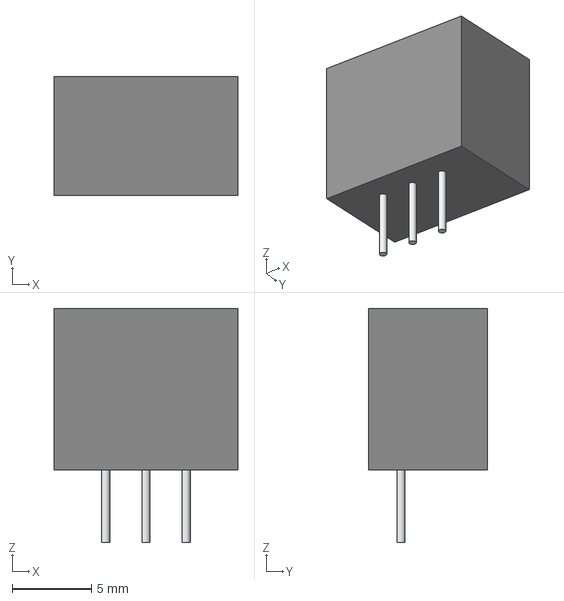
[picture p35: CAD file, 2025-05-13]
hard/Footprint/TSR_1_2433E/AltiumDesigner/TSR1E_TRP.step
11.6 x 7.50 x 14.8 mm

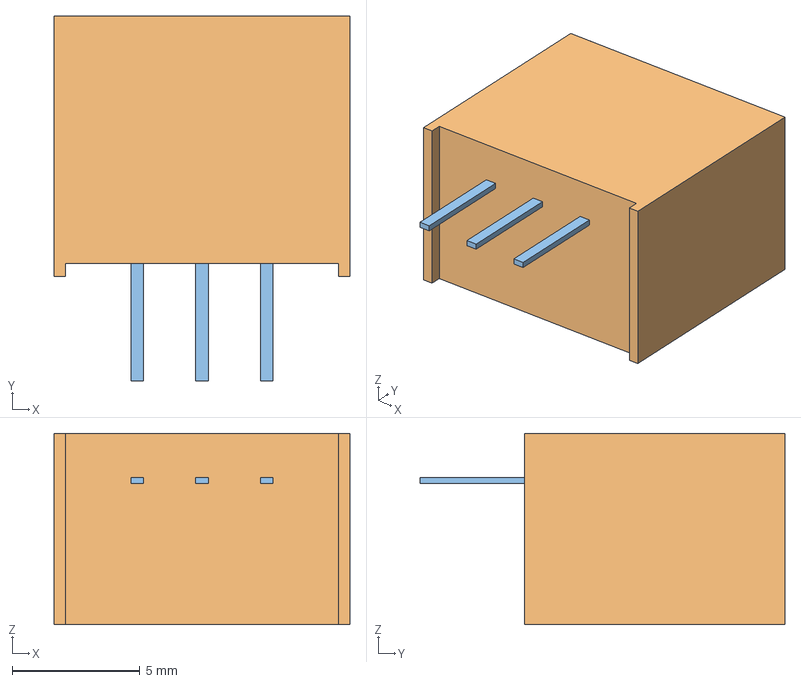
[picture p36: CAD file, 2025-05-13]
hard/Footprint/TSR_1_2433E/tsr1e_3d_drawing.stp
11.6 x 14.3 x 7.50 mm

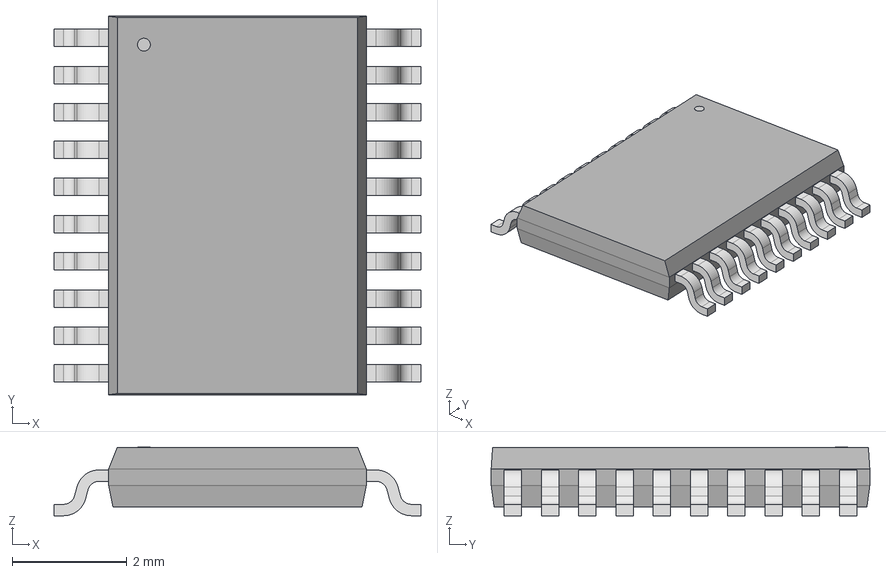
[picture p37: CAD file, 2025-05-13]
hard/Footprint/ul_AT42QT2120-XU/AltiumDesigner/TSSOP20_MC_MCH.step
6.40 x 6.60 x 1.20 mm

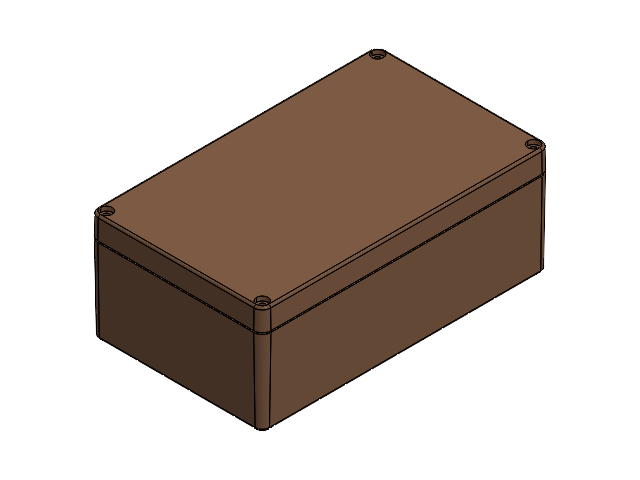
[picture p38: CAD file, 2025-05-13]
Mec/PN-1334_Copie.SLDASM
1334-C.STEP
1334-B.STEP

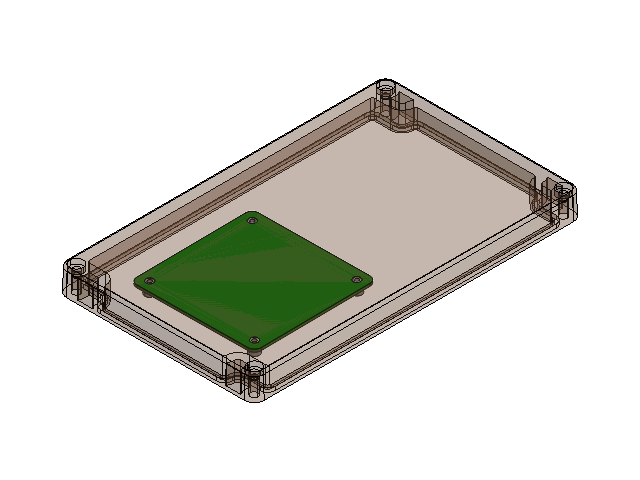
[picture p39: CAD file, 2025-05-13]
Mec/AssemblyTest.SLDASM
1334-C.STEP
9774050360.step x 4
Mid_Body-0_1.step x 8
Mark_1.step x 8
Mid_Body-2_1.step x 2
Mark-3_1.step x 2
5502443216_1.step
Geh___e_10_1.step
Verschluss_10_1.step
Pin1_1.step x 10
Pin_rechts_1.step
Pin_rechts_mir_1.step

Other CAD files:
Mec/testaaaa.SLDASM
Mec/PN-1334.STEP.SLDASM
hard/Footprint/AT42QT2120_SU/SOIC20-W_MC_MCH.step
hard/Footprint/AT42QT2120_XUR/TSSOP20_MC_MCH.step
hard/Footprint/J104D2C3VDC_20S/RELAY_J104D2C3VDC_20S_CRS.step
hard/Footprint/MAX17554AATA_/AltiumDesigner/21-0487_T822CN+1_ADI.step
Mec/2414_TouchCapa.step
Mec/ES_PCB_6C_2L_2023.DXF
Mec/PN-1334.STEP
Mec/test capa.SLDASM
Mec/test capa.step
Mec/test_capa.step
Mec/testafrfr.DXF
hard/Footprint/QBLP631_MONO (1)/QBLP631_MONO.iges
hard/Footprint/QBLP631_MONO/QBLP631_MONO.iges
hard/Footprint/ZVP4525ZTA (1)/ZVP4525ZTA.step
hard/Footprint/ZVP4525ZTA/AltiumDesigner/SOT-89-3_4P5X2P6_DIO.step

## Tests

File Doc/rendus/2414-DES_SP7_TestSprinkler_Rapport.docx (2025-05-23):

Travail de semestre

Ecole supérieure

Électronique

Réalisé par : A l’attention de :

Aymeric Clauzel Moreno Juan José

Castoldi Serge

Schubert Edouard

Dates :

Début du travail : 19.08.2024

Fin :

# 1 Table des matières :

# 2 Pré-étude :

## 2.1 Introduction :

Au cours de cette deuxième année à l’ETML-ES, un projet de semestre nous est attribué. Certains proviennent de clients extérieurs tels que DES sécurité.

Dans le cadre de ce projet il nous est d’abord demander de faire le cahier des charge.

Cette phase de pré-étude permet pour ma part de clarifier le cahier des charge transmis. Pour ma part 2 cahier des charges m’ont été transmis l’un par M. Schubert, l’autre part M. Moreno, ce qui ne simplifie pas la chose.

Cette pré-étude a été faite avec peu de compréhension des domaine « détection incendie » et des normes en découlant n’y ayant jamais été confronté. Le document évoluera après le rendus et le rapport pour devenir le rapports final. Elle sert de « proposition » au client et évolue au fils des discussions.

## 2.2 Cahier des charges :

Voir les annexes physique : « dossier rouge » & « DES SPB 7 Test Sprinkler 2124 »

Cahier des charges final, voir annexe : « 2414-DES_SPB_7_TestSprinkler-CDC »

## 2.3 Schéma général du système :

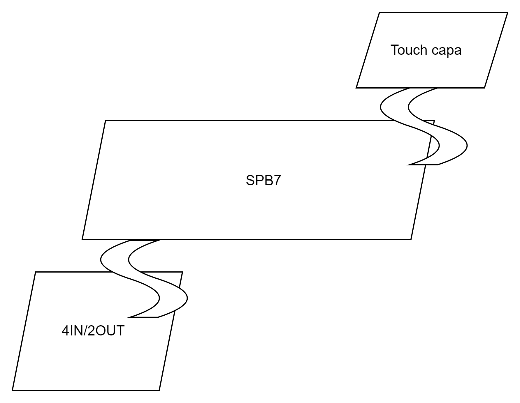
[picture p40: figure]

Le système à réaliser se présente en deux différent PCB « TouchCapa » et « SPB7 » dans la figure de gauche.

Le PCB « 4IN/2Out » de la marque HoneyWell est fournis par M. Schubert. Et doit venir se monter directement sur le « SPB7 ». Quant au « TouchCapa » il doit se trouver directement contre le couvercle du boitier.

Figure 1 Principe

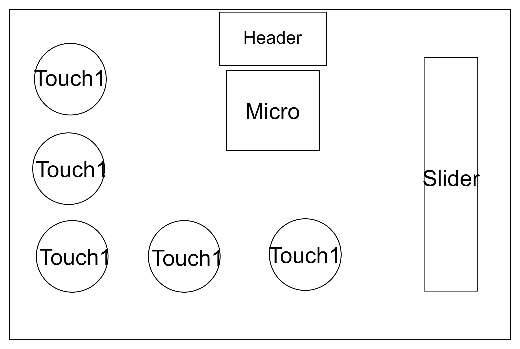
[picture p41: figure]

Le PCB « TouchCapa » auras pour but de rester très « vide » avec le strict nécessaire. La contrainte mécanique permet d’assurer la détection l’ors de l’appuis.

Figure 2 touch capa

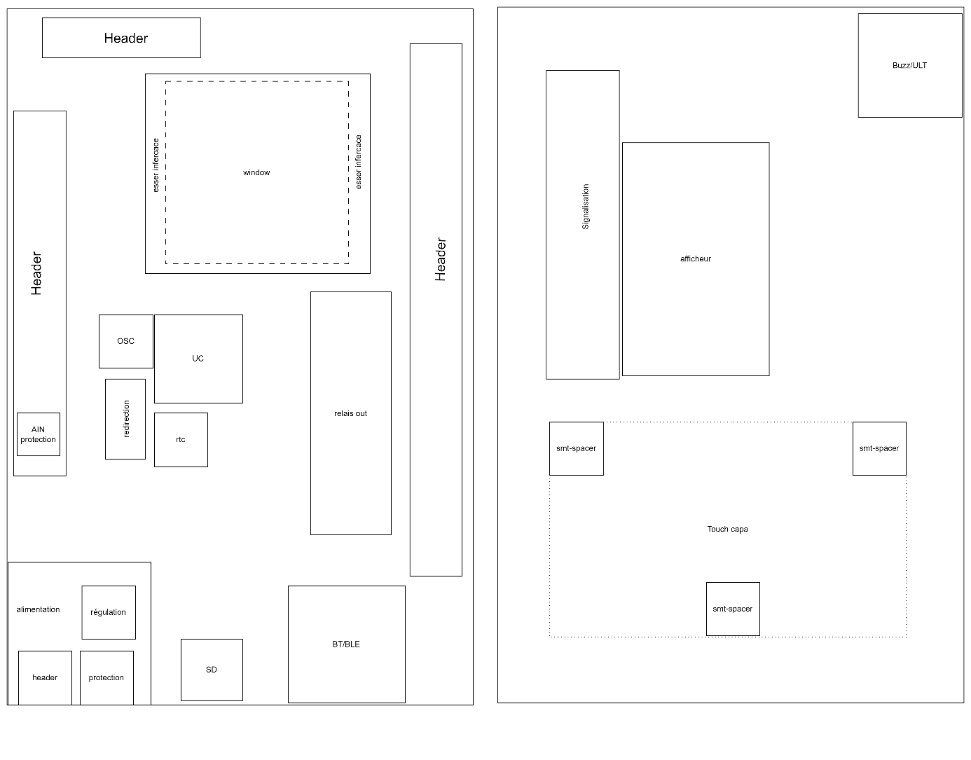
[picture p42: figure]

Figure 3 SPB7

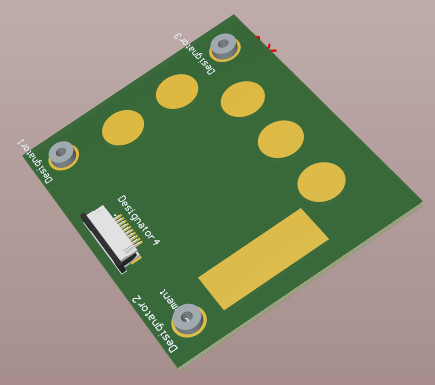
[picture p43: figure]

Pour visualiser l’encombrement dans le boitier une des première chose importante est de déjà ajouter des composants aux fichier d’assemblage du boitier transmis par M. Moreno.

Figure 4 une idée du Touchcapa

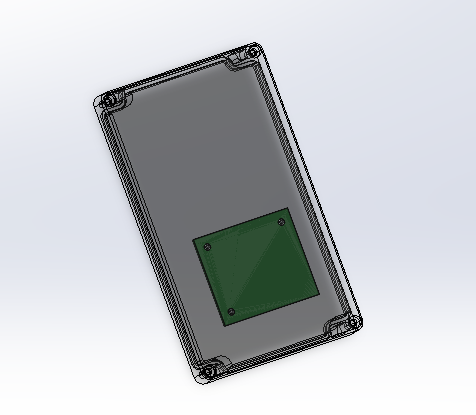
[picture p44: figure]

Figure 5idée d ela place prise

## 2.4 Schéma bloc hardware :

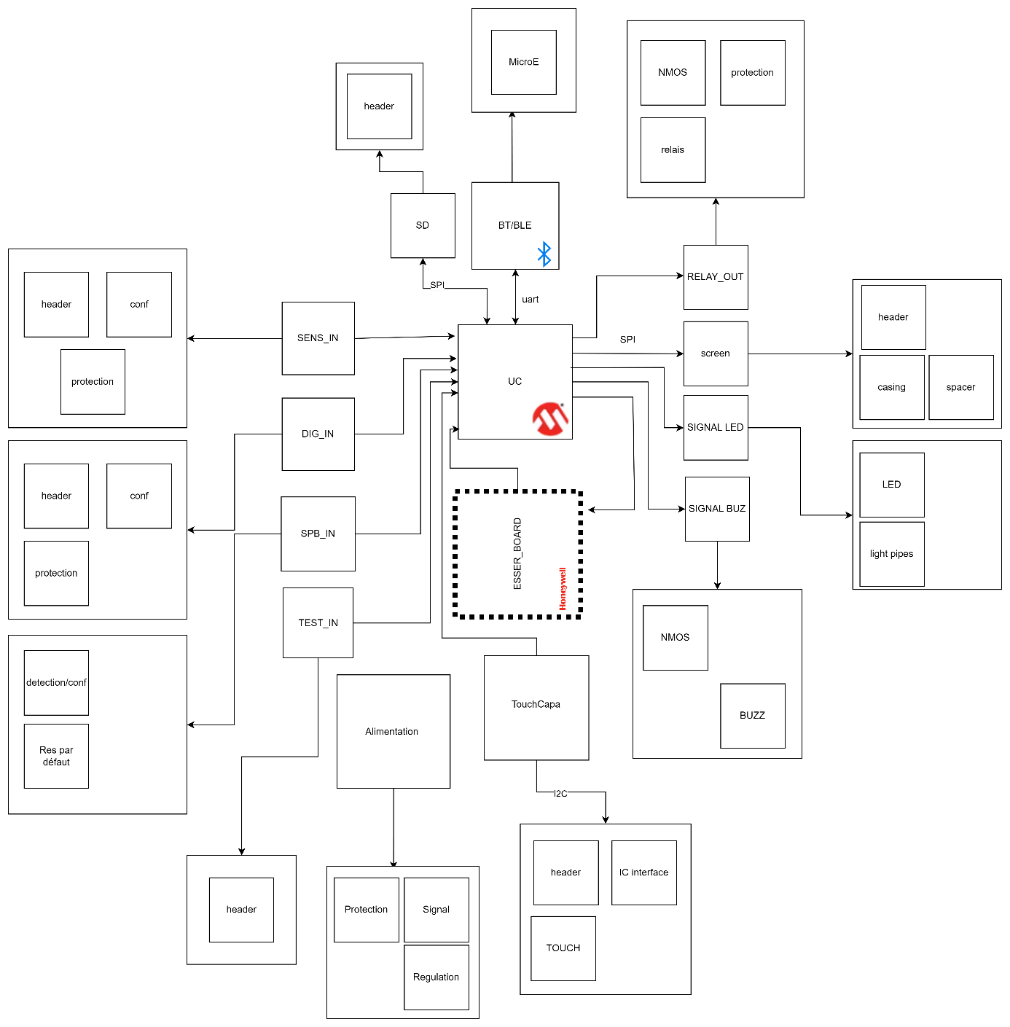
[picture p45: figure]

Figure 6 schéma bloc

## 2.5 Choix technologiques :

Avant de parler des choix, commençons par les choses imposées et les choix en découlant. Tout d’abord le système se doit pouvoir intégrer un module existant de chez Honeywell, le « esserbus alarm transponder, 4 IN/2 OUT ». Ce module a été fournis avec les documents disponible lors de l’achat.

Figure 7 4In/2Out board

Le boitier doit avoir un couvercle transparent. Et par chance a été fournis par M.Moreno :

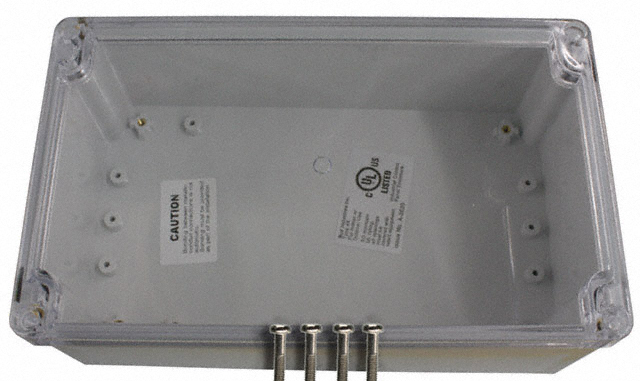
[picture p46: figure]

Ce boitier de chez Bud Industries fait 200mm x 119,99 mm pour 75,13mm de haut, en PC (polycarbonates) plastic. Avec une épaisseur de 3,05mm, et un couvercle transparent. De plus le boitier possède des inserts pours montage et le statut actif.

Figure 8 PN-1334-C

Les connecteurs :

Une demande est que les connecteur fils-à carte ne sois pas à vis (terminal block). Vis-à-vis de cette demande, j’ai eu l’occasion de confirmer le type connecteur, grâce à une visite de Schubert. les connecteurs utilisés :

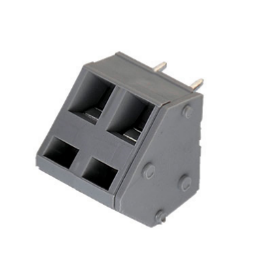
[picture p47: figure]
691413720002B

Le choix s’est prononcé pour la simplicité d’utilisation, un tournevis permettant d’actionner le ressort. Ce connecteur accepte des fils de 10 à 28 AWG, ce qui correspond au 0,8mm demandés pour les câbles U72

Figure 9 691413720002B

Fixation mécanique :

Entre les cartes des spacer SMD avec filetage M3 serons surement utilisées, cars si bien montés, ils apportent l’avantage de pouvoir géré l’espacement avec d’autre pcb via des entretoises ou autres solutions choisies plus tard (le modèle final reste à définir):

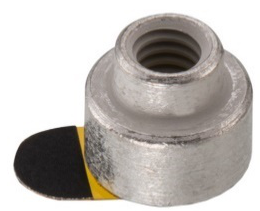
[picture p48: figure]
9774025243R

Figure 10 9774020360R

Pour les TouchCapa :

l’IC imposé est le AT42QT2120, de chez Atmel, il permet jusqu’à 9 touches + une Wheel/slider, ce qui semble sympa à tester. Le nombre de touche étant laissé à définir mon envie est d’ajouter au moins un slider si la place le permet. La figure ci-dessous, montre que le boitier ne sera pas un problème pour la détection des touches ou du slider.

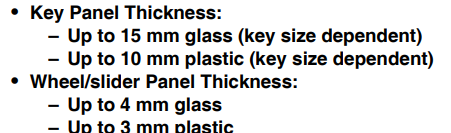
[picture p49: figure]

Figure 11AT42QT2120

Le choix des connecteurs carte à carte :

Servant à relier les PCB « TouchCapa » & « MainBoard », a été orienté par M. Moreno, mon choix s’est précisé, pour la facilité d’accessibilité à déclencher l’étrier depuis le dessus. Les choix du connecteur :

WR-FPC 1.00 mm SMT ZIF Horizontal Bottom Contact

Validés par M. Schubert ces connecteurs de chez Wurth, 10 position pour câble plats de 3mm de haut pour 17mm de long

Figure 12 68611014422

Logger de data :

Un socle pour carte microSD a été choisi car il me semblait judicieux, dans l’idée ou les données pourraient être lues sur différents systèmes style laptop smartphone tablette.

Les protections :

A propos des protection des entrées le choix n’as pas encore été fait entre diodes zener ou TVS. L’idée d’optocoupleur reste en suspens pour les entrées digitales mais dans l’idée permettant d’appliquer un rapport directement aux tensions lues, mais impliquerais des une baisse de réactivité du système, et pour des raisons de couts.

Régulation :

L’alimentation du module Esser est de 10-28V, l’utilisation d’un buck semble propice puisque que la demande de M.Schubert est que le systèmes puisse fonctionner entre 10-42V. Le choix n’a pas encore été fait.

La rtc :

La carte utilisée pour les TP de l’école seras prise comme exemple, car elle est fonctionnelle et que les composant sont disponibles. A voir pour trouver une RTC en SPI, ce qui permettrais de réduire le nombre de pins.

Des light pipes :

Pour améliorer la diffusion l’utilisation de light pipe est validée par M. Schubert, le modèle précis n’est pas encore défini.

Le microcontrôleur :

Dans la hâte le même microcontrôleur me semble être le plus adéquat, il permet l’utilisation du Protocol USB, possède un AD, et la vitesse nécessaire afin d’avoir l’occasion de séparer les différentes fonctionnalités par port, le choix demande à être précisé. Le courant max que peux fournir le microcontrôleur est de 200mA, pour piloter les led une estimation faite est ~5mA par LED ce qui ferais un peux moins de 100mA au total. Le format 100 pin étant disponible, ne connaissant pas de microcontrôleur avec autant d’entrée ou sortie sans l’utilisation d’io extander, c’est sur cette solution que je me dirige dépassant les 64 pins avant d’avoir fini cette pré-étude.

Relais :

Des relais dans le format de ceux du module 4in/2out ont été choisi, avec une tension de commande de 3,3V, les relais piloterons une tensions de 10V avec un courant max de 2A. Ils font 20x10x11mm ce qui semble adéquat vu le nombre devant être à disposition. Des relais de secours avec un format plus petit ont été choisi mais un courant de commutation de 1A max, ceux-ci mesurent 10,6X5,3X6,5mm.

Le moyens de connecter le module Esser reste encore à trouver, la fenêtre est quasiment certaine pour laisser l’espacement des composants, mais le moyens de fixation qui assure une connexion optimale reste encore à trouver

## 2.6 Interaction avec le monde :

Les entrées :

Les TouchCapa :

Une des consigne qui m’a été donné étais d’utiliser le projet « » de M.Cohello, de le mettre en service et l’utiliser pour tester la détection aux travers d’une paroi de boitier « « de « « d’épaisseur. Des mesures ont été faite grâce à l’aide de M. Castoldi, qui ont permis de valider l’utilisation de ce microcontrôleur et des touches capacitives conseillées. Voir résultats

en annexe

Pour les PCB, il me fallait d’abords connaitre les dimensions pour faire une estimation. Pour le « TouchCapa », une touche devant faire la taille d’un doigt (~10mm de diamètre), selon la disposition plus haut un pcb en figure XX, une estimation de la taille serais 60mm x 70 mm

1051620x01

Concernant le SPB7, je vais tenter de faire le plus grand possible pour avoir le maximum d’espace pour les connecteurs et relais quitte à réduire la taille au fur et à mesure du design (pour le SPB7).

Figure 13 1051620001

Une carte SD doit être disponible pour « logger » les données et permettre l’analyse postérieure, le choix du connecteur a déjà été fait, le plus petit possible pour laisser la place aux header et aux relais :


Figure 14 RN4678 Click

Le module Bluetooth :

L’école étant familière à l’utilisation des module MikroE, je n’ai pas cherché d’autre alternatives face aux arguments, tels que la simplicité à changer de protocole de communication avec des adaptation software. Le module, il mesure 43x25,4mm :

Mikroe Wireless Connectivity RN4678 click front

Concernant la signalisation sonore :

il est demandé d’ajouter un buzzer. Dans un boitier hermétiquement fermés, le son ne dois surement pas bien se propager, j’ai donc décider d’ajouter une proposition/alternative, ajouter un transducteur ultrason pour tenter de faire résonner le boitier à une fréquence audible. Après avoir fait un test à la maison sans aop, avec juste le transduceur directement connecter sur une entrée TTL j’ai réalisé que dans un boitier ou non c’est le transduceur lui-même qui émet le sons, malgré qu’il soit audible dans l’état c’est inutilisable. Peut-être avec un actionneur piezzo. Dommage de ne pas avoir pris plus de temps pour faire plus de différents tests. Aucun composant n’a encore été choisi.

Les switch de configuration :

Encore une fois grâce un M. Moreno, un choix a été fait malheureusement j’ai préféré chercher une option un peu moins cher en restant dans l’idée d’utiliser des commutateur au lieu de cavalier, pour faciliter l’utilisation et la configuration lors de l’installation du système. :

Figure 15 SLW-913535-2A-SMT

Les sorties :

Moniteur graphique :

En discutant avec M. Schubert j’ai compris que l’afficheur servait à « nommée » les Signaux aux entrées des 5 entrées libres. Les plus grand LCD « standards » utilisé à l’ES n’ont que 4 lignes, nous avons donc décider de partir sur un LCD graphique. Lequel a été choisi dans la foulée :

Figure 16 NHD-C12864LZ-FSW-FBW-3V3

Les voyants :

Ils n’ont pas encore été choisi mais le but est de trouver des voyant qui consomment environs 5 mA chacun. Au nombre de 17 de couleurs différentes. 2 Led de vie ont été ajoutée, celle de la partie alimentation qui est « bête » et celle de vie du microcontrôleur (Controller par ce dernier)

- 5 Free_IN, orange
- 1 Vanne IN orange
- 1 rouge in presostat
- 7 blanche save
- 1 verte LIFE_SYS indication
- 1 BT bleue
- 1 verte ALIM vie

## 2.7 Évaluation des couts :

## 2.8 Planning :

## 2.9 Conclusion & perspectives :

Beaucoup de temps est nécessaires à la mise en place rien que du cahier des charges de ce projet, qui semble être un projets plutôt complet, mes estimations lors de la planification sont à revoir. De plus il semble compliquer d’arriver à une solution fiable et fonctionnel du premier coup en si peu de temps prenant en considération le temps nécessaire à la compréhension du sujet, ainsi qu’aux choix à faire restant.

En effet la méthode de détection d’interruption de ligne reste encore à définir avec la méthode pull-up/dow + zener.

Notamment les presses étoupes.

La manière dont les résistances 10k pour fermer les boucles / contact SPB_IN, seront mis en place (manuelle/automatique).

Les protections des entrées ne sont pas encore clairement définies, ainsi que les protections des relais (Schottky ou pas ?), Sans penser aux sur multiples oublis de ma parts lors de cette pré-étude. la pré-étude n’étant pas terminée il est prioritaire de finir les test nécessaires et validé les choix faits jusqu’ici, pour aller de l’avant.

perspectives :

Difficile de se projeter, alors autant se concentrer sur ce qui reste à portée.

L’esthétique globale seras une chose importante, la possibilité d’un stickers pour la face avant doit être proposée. Je m’y suis surement pris un peu trop à la cool pour le départ de ce projet, il reste des tonnes de travail à abattre et peu de temps pour le faire. Je crains de ne pas réussir à fournir de résultat.

### 2.9.1 Retour sur la présentation:


À la suite de ces retours :

Des recherches ont été faites, le projet doit-il suivre les normes de détection incendie. N’ayant pas accès aux normes ni extraits (EN54), la vue d’ensemble manquera toujours.

Concernant la solution USB, le choix d’un FTD231 est fait, car j’ai choisi de ne pas changer les habitudes de l’ES, d’utiliser un chip qui simplifie la vie.

Depuis la présentation, je suis revenu sur mon choix de ne pas utiliser d’optocoupleur, car au fils des recherches j’ai trouvé des optocoupleurs linéaires utiliser dans les boucle de courant.

Et finalement après conseils de Mr Moreno, je suis revenu encore une fois sur ce choix.

La RTC sera alimenter par l’entrée du système travers du régulateur avec de grande capacités de découplage.

# 3 Design

## 3.1 Microcontrôleur

Suite à la présentation, le conseil était d’utiliser le même microcontrôleur du starter kit utiliser pour la formation en deuxième année disponible dans le projet n°11020E.


L’avantage est que j’ai pu récupérer pas mal de partie de schéma supposément juste. Car fournis par nos enseignants. Comme la RTC, la carte SD, les différents oscillateur, l’interface UART, le module MIKROE, la partie de reset et debug,

## 3.2 Entrée spéciales :

Pour la manière de lire les contact secs, j’ai d’abord voulu utiliser les pull-ups et pull-downs du microcontrôleur. En effectuant des recherches sur les valeurs dans le datasheet du microcontrôleur (figure du dessous), j’ai pu trouver cette information, dans un forum, quelqu’un expliquait qu’il fallait plus les vois comme des sources de courant. J’ai pensé plus sûr, d’utiliser un autre moyens pour être sûr de fournir suffisamment de courant.

J’ai d’abord penser récuperer la source de courant de servant à alimenter la backlight du projet n°11020, étant une source de courant 20mA, ajouter un suiveur et une resistance de 500Ω reviendrais à au même que la lecture des capteur 4-20mA, en recalculant la résistance en parallèle de la jonction du transitor pour le courant voulus. Suivit d’un suiveur, et d’une résistance.


Voyant le nombre de composants, et le nombre d’entrée à lire, j’ai changé d’avis pour simplifier le tout, utiliser simplement 3 résistance de 100 Ω.


Le cas critique étant le moment ou la ligne est coupée, uniquement la résistance de « pull-up » limitera le courant. Le courant admissible par les entrée du microcontrôleur choisit est d’environ 15mA maximum d’après le tableau ci-dessous.


J’ai pensé à garder l’aop et ajouter un gain de 0.5 par exemple, pour finalement décider de choisir une résistance de 330Ω

res | ligne coupée | | contact ouvert | | contact fermer
| U | I | U | I | U | I
100 | 3,3 | 0,033 | 1,98 | 0,00792 | 1,65 | 0,0066
330 | 3,3 | 0,01 | 1,1 | 0,002222222 | 1,65 | 0,003333

Un des avantage est que les entrée avec nécessité du dispositif EOL-R sont « compatible » avec la lecture des contact sec, la différence est la nécessité des entrées analogiques permettant de lires les différents niveaux de tension. Alors que pour la lecture des contact sec une pull-up suffit. Le courant étant « contrôler », malheureusement est-ce que 10mA suffirons ?

## 3.3 Bluetooth

Une des demande qui m’a été faite est de trouvé une alternative pour le module bluetooth. Celle que j’ai trouvée semble adéquate mais au vue des pin à dispositions sur le microcontrôleur une discussions est nécessaires. Car dans l’idée, il me fallait ajouter les empreintes des 2 modules pour plus tard, choisir lequel monter lors de l’assemblage. Une solution serait de ne pas mettre l’empreinte du module mikroE, uniquement celui du module. Ou ajouter un I/O extander pour piloter les leds de signalisation, et laisser de l’espace directement sur le microcontrôleur


## 3.4 Sortie relais

Pour piloter les relais, un MOS N, avec une résistance série, et une pull-down, pour figer l’état à 0V. et une diode de roue libre 1N4001, car je ne pense pas qu’une Schottky soit nécessaires.


## 3.5 Entrées analogique

Le but du montage permet la lecture d’un capteur 0-10V entre 0 et 3,3V c’est un simple pont diviseur 1/3. Lorsque le commutateur est enclenché la résistance de 500Ω mise en parallèle fixe la tension sur le pont à 10V 10/(0,02)=500 . Ce qui permet de lire la tension une fois encore entre 0 et 3V.


## 3.6 Protection

Les diodes TVS choisies sont celle à disposition dans le stock de l’ES qui nous à été conseiller d’utiliser pour ces projets. Elles ont été placées sur les entrée analogiques, les entrées destinées à d’autres SPB, et sur les entrée « Spéciales » « SPE_IN ».

## 3.7 Switch de configuratio4n

Pour la redirection des signaux sur la sortie de dérangements une série de switch directement reliés à des pull-up / pull-down.


## 3.8 PCB TOUCH_CAPA

Pour le pcb touch capca, il reste simple avec comme exemple le projet n°2123 Démonstrateur de panneau Touch. Les résistances ont été sélectionnées à la valeur minimale recommandée par le datasheet pour apporter le plus de sensibilité possible.


## 3.9 Réalisation

### 3.9.1 Routage du PCB :

#### 3.9.1.1 Points critiques ou particuliers

Paire diiff – passage led cmd

Montage R array under relay

### 3.9.2 Montage

J’ai voulu adopté une statégie de monter certains composant par fonctionalité pour les tester au fu et à mesure. Sans connecteur de sortie

Microcontroleur – sortie -test alim labo 3,3V max 50mA

Alim – 30V max 2A

Buzzer

Entrée TVS

Entrée analogique

Registre a décalage

RTC

Relay cmd

SD

### 3.9.3 Mise en service

Microcontroleur – sortie toggle out + led life

Alim

Buzzer

Entrée analogique

Registre a décalage

Relay cmd

RTC

At this time PCB died…

//Touchcapa sould be after analog_in cause esier

//SD

//Screen

//Bluetooth

### 3.9.4 Programmation logicielle

Buzzer Timer + toggle out

Analog in – ADC read all out and calculation : Vref/resolution * 1/3*Vmesured

Like 3v in should be measured around

### 3.9.5 Tests et mesures

### 3.9.6 Modifications hardware :

Buzzer

Microcontroleur pinning

Registre a décalage

Relay cmd

Connectors mirroring

Resistor array

#### 3.9.6.1 Raisons

#### 3.9.6.2 Documentation des changements

## 3.10 Validation

### 3.10.1 Résultats des tests

### 3.10.2 Fonctionnement général

### 3.10.3 Problèmes rencontrés / Résolutions

## 3.11 Analyse de durabilité

### 3.11.1 Aspects environnementaux

### 3.11.2 Aspects sociaux

### 3.11.3 Aspects économiques

## 3.12 Conclusion

### 3.12.1 Bilan global

### 3.12.2 Compétences acquises

### 3.12.3 Améliorations possibles / suite du projet

## 3.13 Annexes

### 3.13.1 Cahier des charges initial

### 3.13.2 Fichiers de CAO (schémas, PCB, implantation)

### 3.13.3 Liste des pièces et coûts réels

### 3.13.4 Extraits essentiels du code

### 3.13.5 Planning initial vs réel

### 3.13.6 Journal de travail

### 3.13.7 Mode d'emploi du système

Lausanne, le 09.11.2024

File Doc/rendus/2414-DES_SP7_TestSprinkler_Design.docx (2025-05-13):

Travail de semestre

Ecole supérieure

Électronique

Réalisé par : A l’attention de :

Aymeric Clauzel Moreno Juan José

Castoldi Serge

Schubert Edouard

Dates :

Début du travail : 19.08.2024

Fin :

# 1 Table des matières :

# 2 Pré-étude :

## 2.1 Introduction :

Au cours de cette deuxième année à l’ETML-ES, un projet de semestre nous est attribué. Certains proviennent de clients extérieurs tels que DES sécurité.

Dans le cadre de ce projet il nous est d’abord demander de faire le cahier des charge.

Cette phase de pré-étude permet pour ma part de clarifier le cahier des charge transmis. Pour ma part 2 cahier des charges m’ont été transmis l’un par M. Schubert, l’autre part M. Moreno, ce qui ne simplifie pas la chose.

Cette pré-étude a été faite avec peu de compréhension des domaine « détection incendie » et des normes en découlant n’y ayant jamais été confronté. Le document évoluera après le rendus et le rapport pour devenir le rapports final. Elle sert de « proposition » au client et évolue au fils des discussions.

## 2.2 Cahier des charges :

Voir les annexes physique : « dossier rouge » & « DES SPB 7 Test Sprinkler 2124 »

Cahier des charges final, voir annexe : « 2414-DES_SPB_7_TestSprinkler-CDC »

## 2.3 Schéma général du système :


Le système à réaliser se présente en deux différent PCB « TouchCapa » et « SPB7 » dans la figure de gauche.

Le PCB « 4IN/2Out » de la marque HoneyWell est fournis par M. Schubert. Et doit venir se monter directement sur le « SPB7 ». Quant au « TouchCapa » il doit se trouver directement contre le couvercle du boitier.

Figure 1 Principe


Le PCB « TouchCapa » auras pour but de rester très « vide » avec le strict nécessaire. La contrainte mécanique permet d’assurer la détection l’ors de l’appuis.

Figure 2 touch capa


Figure 3 SPB7


Pour visualiser l’encombrement dans le boitier une des première chose importante est de déjà ajouter des composants aux fichier d’assemblage du boitier transmis par M. Moreno.

Figure 4 une idée du Touchcapa


Figure 5idée d ela place prise

## 2.4 Schéma bloc hardware :


Figure 6 schéma bloc

## 2.5 Choix technologiques :

Avant de parler des choix, commençons par les choses imposées et les choix en découlant. Tout d’abord le système se doit pouvoir intégrer un module existant de chez Honeywell, le « esserbus alarm transponder, 4 IN/2 OUT ». Ce module a été fournis avec les documents disponible lors de l’achat.

Figure 7 4In/2Out board

Le boitier doit avoir un couvercle transparent. Et par chance a été fournis par M.Moreno :


Ce boitier de chez Bud Industries fait 200mm x 119,99 mm pour 75,13mm de haut, en PC (polycarbonates) plastic. Avec une épaisseur de 3,05mm, et un couvercle transparent. De plus le boitier possède des inserts pours montage et le statut actif.

Figure 8 PN-1334-C

Les connecteurs :

Une demande est que les connecteur fils-à carte ne sois pas à vis (terminal block). Vis-à-vis de cette demande, j’ai eu l’occasion de confirmer le type connecteur, grâce à une visite de Schubert. les connecteurs utilisés :

691413720002B

Le choix s’est prononcé pour la simplicité d’utilisation, un tournevis permettant d’actionner le ressort. Ce connecteur accepte des fils de 10 à 28 AWG, ce qui correspond au 0,8mm demandés pour les câbles U72

Figure 9 691413720002B

Fixation mécanique :

Entre les cartes des spacer SMD avec filetage M3 serons surement utilisées, cars si bien montés, ils apportent l’avantage de pouvoir géré l’espacement avec d’autre pcb via des entretoises ou autres solutions choisies plus tard (le modèle final reste à définir):

9774025243R

Figure 10 9774020360R

Pour les TouchCapa :

l’IC imposé est le AT42QT2120, de chez Atmel, il permet jusqu’à 9 touches + une Wheel/slider, ce qui semble sympa à tester. Le nombre de touche étant laissé à définir mon envie est d’ajouter au moins un slider si la place le permet. La figure ci-dessous, montre que le boitier ne sera pas un problème pour la détection des touches ou du slider.


Figure 11AT42QT2120

Le choix des connecteurs carte à carte :

Servant à relier les PCB « TouchCapa » & « MainBoard », a été orienté par M. Moreno, mon choix s’est précisé, pour la facilité d’accessibilité à déclencher l’étrier depuis le dessus. Les choix du connecteur :

WR-FPC 1.00 mm SMT ZIF Horizontal Bottom Contact

Validés par M. Schubert ces connecteurs de chez Wurth, 10 position pour câble plats de 3mm de haut pour 17mm de long

Figure 12 68611014422

Logger de data :

Un socle pour carte microSD a été choisi car il me semblait judicieux, dans l’idée ou les données pourraient être lues sur différents systèmes style laptop smartphone tablette.

Les protections :

A propos des protection des entrées le choix n’as pas encore été fait entre diodes zener ou TVS. L’idée d’optocoupleur reste en suspens pour les entrées digitales mais dans l’idée permettant d’appliquer un rapport directement aux tensions lues, mais impliquerais des une baisse de réactivité du système, et pour des raisons de couts.

Régulation :

L’alimentation du module Esser est de 10-28V, l’utilisation d’un buck semble propice puisque que la demande de M.Schubert est que le systèmes puisse fonctionner entre 10-42V. Le choix n’a pas encore été fait.

La rtc :

La carte utilisée pour les TP de l’école seras prise comme exemple, car elle est fonctionnelle et que les composant sont disponibles. A voir pour trouver une RTC en SPI, ce qui permettrais de réduire le nombre de pins.

Des light pipes :

Pour améliorer la diffusion l’utilisation de light pipe est validée par M. Schubert, le modèle précis n’est pas encore défini.

Le microcontrôleur :

Dans la hâte le même microcontrôleur me semble être le plus adéquat, il permet l’utilisation du Protocol USB, possède un AD, et la vitesse nécessaire afin d’avoir l’occasion de séparer les différentes fonctionnalités par port, le choix demande à être précisé. Le courant max que peux fournir le microcontrôleur est de 200mA, pour piloter les led une estimation faite est ~5mA par LED ce qui ferais un peux moins de 100mA au total. Le format 100 pin étant disponible, ne connaissant pas de microcontrôleur avec autant d’entrée ou sortie sans l’utilisation d’io extander, c’est sur cette solution que je me dirige dépassant les 64 pins avant d’avoir fini cette pré-étude.

Relais :

Des relais dans le format de ceux du module 4in/2out ont été choisi, avec une tension de commande de 3,3V, les relais piloterons une tensions de 10V avec un courant max de 2A. Ils font 20x10x11mm ce qui semble adéquat vu le nombre devant être à disposition. Des relais de secours avec un format plus petit ont été choisi mais un courant de commutation de 1A max, ceux-ci mesurent 10,6X5,3X6,5mm.

Le moyens de connecter le module Esser reste encore à trouver, la fenêtre est quasiment certaine pour laisser l’espacement des composants, mais le moyens de fixation qui assure une connexion optimale reste encore à trouver

## 2.6 Interaction avec le monde :

Les entrées :

Les TouchCapa :

Une des consigne qui m’a été donné étais d’utiliser le projet « » de M.Cohello, de le mettre en service et l’utiliser pour tester la détection aux travers d’une paroi de boitier « « de « « d’épaisseur. Des mesures ont été faite grâce à l’aide de M. Castoldi, qui ont permis de valider l’utilisation de ce microcontrôleur et des touches capacitives conseillées. Voir résultats

en annexe

Pour les PCB, il me fallait d’abords connaitre les dimensions pour faire une estimation. Pour le « TouchCapa », une touche devant faire la taille d’un doigt (~10mm de diamètre), selon la disposition plus haut un pcb en figure XX, une estimation de la taille serais 60mm x 70 mm

Concernant le SPB7, je vais tenter de faire le plus grand possible pour avoir le maximum d’espace pour les connecteurs et relais quitte à réduire la taille au fur et à mesure du design (pour le SPB7).

1051620x01

Une carte SD doit être disponible pour « logger » les données et permettre l’analyse postérieure, le choix du connecteur a déjà été fait, le plus petit possible pour laisser la place aux header et aux relais :


Figure 13 1051620001

Mikroe Wireless Connectivity RN4678 click front

Figure 14 RN4678 Click

Le module Bluetooth :

L’école étant familière à l’utilisation des module MikroE, je n’ai pas cherché d’autre alternatives face aux arguments, tels que la simplicité à changer de protocole de communication avec des adaptation software. Le module, il mesure 43x25,4mm :

Concernant la signalisation sonore :

il est demandé d’ajouter un buzzer. Dans un boitier hermétiquement fermés, le son ne dois surement pas bien se propager, j’ai donc décider d’ajouter une proposition/alternative, ajouter un transducteur ultrason pour tenter de faire résonner le boitier à une fréquence audible. Après avoir fait un test à la maison sans aop, avec juste le transduceur directement connecter sur une entrée TTL j’ai réalisé que dans un boitier ou non c’est le transduceur lui-même qui émet le sons, malgré qu’il soit audible dans l’état c’est inutilisable. Peut-être avec un actionneur piezzo. Dommage de ne pas avoir pris plus de temps pour faire plus de différents tests. Aucun composant n’a encore été choisi.

Les switch de configuration :

Encore une fois grâce un M. Moreno, un choix a été fait malheureusement j’ai préféré chercher une option un peu moins cher en restant dans l’idée d’utiliser des commutateur au lieu de cavalier, pour faciliter l’utilisation et la configuration lors de l’installation du système. :

Figure 15 SLW-913535-2A-SMT

Les sorties :

Moniteur graphique :

En discutant avec M. Schubert j’ai compris que l’afficheur servait à « nommée » les Signaux aux entrées des 5 entrées libres. Les plus grand LCD « standards » utilisé à l’ES n’ont que 4 lignes, nous avons donc décider de partir sur un LCD graphique. Lequel a été choisi dans la foulée :

Figure 16 NHD-C12864LZ-FSW-FBW-3V3

Les voyants :

Ils n’ont pas encore été choisi mais le but est de trouver des voyant qui consomment environs 5 mA chacun. Au nombre de 17 de couleurs différentes. 2 Led de vie ont été ajoutée, celle de la partie alimentation qui est « bête » et celle de vie du microcontrôleur (Controller par ce dernier)

- 5 Free_IN, orange
- 1 Vanne IN orange
- 1 rouge in presostat
- 7 blanche save
- 1 verte LIFE_SYS indication
- 1 BT bleue
- 1 verte ALIM vie

## 2.7 Évaluation des couts :

## 2.8 Planning :

## 2.9 Conclusion & perspectives :

Beaucoup de temps est nécessaires à la mise en place rien que du cahier des charges de ce projet, qui semble être un projets plutôt complet, mes estimations lors de la planification sont à revoir. De plus il semble compliquer d’arriver à une solution fiable et fonctionnel du premier coup en si peu de temps prenant en considération le temps nécessaire à la compréhension du sujet, ainsi qu’aux choix à faire restant.

En effet la méthode de détection d’interruption de ligne reste encore à définir avec la méthode pull-up/dow + zener.

Notamment les presses étoupes.

La manière dont les résistances 10k pour fermer les boucles / contact SPB_IN, seront mis en place (manuelle/automatique).

Les protections des entrées ne sont pas encore clairement définies, ainsi que les protections des relais (Schottky ou pas ?), Sans penser aux sur multiples oublis de ma parts lors de cette pré-étude. la pré-étude n’étant pas terminée il est prioritaire de finir les test nécessaires et validé les choix faits jusqu’ici, pour aller de l’avant.

perspectives :

Difficile de se projeter, alors autant se concentrer sur ce qui reste à portée.

L’esthétique globale seras une chose importante, la possibilité d’un stickers pour la face avant doit être proposée. Je m’y suis surement pris un peu trop à la cool pour le départ de ce projet, il reste des tonnes de travail à abattre et peu de temps pour le faire. Je crains de ne pas réussir à fournir de résultat.

### 2.9.1 Retour sur la présentation:


À la suite de ces retours :

Des recherches ont été faites, le projet doit-il suivre les normes de détection incendie. N’ayant pas accès aux normes ni extraits (EN54), la vue d’ensemble manquera toujours.

Concernant la solution USB, le choix d’un FTD231 est fait, car j’ai choisi de ne pas changer les habitudes de l’ES, d’utiliser un chip qui simplifie la vie.

Depuis la présentation, je suis revenu sur mon choix de ne pas utiliser d’optocoupleur, car au fils des recherches j’ai trouvé des optocoupleurs linéaires utiliser dans les boucle de courant. Et finalement après conseils de Mr Moreno, je suis revenu encore une fois sur ce choix.

La RTC sera alimenter par l’entrée du système travers du régulateur avec de grande capacités de découplage.

# 3 Design

## 3.1 Microcontrôleur

Suite à la présentation, le conseil était d’utiliser le même microcontrôleur du starter kit utiliser pour la formation en deuxième année disponible dans le projet n°11020E.


L’avantage est que j’ai pu récupérer pas mal de partie de schéma supposément juste. Car fournis par nos enseignants. Comme la RTC, la carte SD, les différents oscillateur, l’interface UART, le module MIKROE, la partie de reset et debug,

## 3.2 Entrée spéciales :

Pour la manière de lire les contact secs, j’ai d’abord voulu utiliser les pull-ups et pull-downs du microcontrôleur. En effectuant des recherches sur les valeurs dans le datasheet du microcontrôleur (figure du dessous), j’ai pu trouver cette information, dans un forum, quelqu’un expliquait qu’il fallait plus les vois comme des sources de courant. J’ai pensé plus sûr, d’utiliser un autre moyens pour être sûr de fournir suffisamment de courant.

J’ai d’abord penser récuperer la source de courant de servant à alimenter la backlight du projet n°11020, étant une source de courant 20mA, ajouter un suiveur et une resistance de 500Ω reviendrais à au même que la lecture des capteur 4-20mA, en recalculant la résistance en parallèle de la jonction du transitor pour le courant voulus. Suivit d’un suiveur, et d’une résistance.


Voyant le nombre de composants, et le nombre d’entrée à lire, j’ai changé d’avis pour simplifier le tout, utiliser simplement 3 résistance de 100 Ω.


Le cas critique étant le moment ou la ligne est coupée, uniquement la résistance de « pull-up » limitera le courant. Le courant admissible par les entrée du microcontrôleur choisit est d’environ 15mA maximum d’après le tableau ci-dessous.


J’ai pensé à garder l’aop et ajouter un gain de 0.5 par exemple, pour finalement décider de choisir une résistance de 330Ω

res | ligne coupée | | contact ouvert | | contact fermer
| U | I | U | I | U | I
100 | 3,3 | 0,033 | 1,98 | 0,00792 | 1,65 | 0,0066
330 | 3,3 | 0,01 | 1,1 | 0,002222222 | 1,65 | 0,003333

Un des avantage est que les entrée avec nécessité du dispositif EOL-R sont « compatible » avec la lecture des contact sec, la différence est la nécessité des entrées analogiques permettant de lires les différents niveaux de tension. Alors que pour la lecture des contact sec une pull-up suffit. Le courant étant « contrôler », malheureusement est-ce que 10mA suffirons ?

## 3.3 Bluetooth

Une des demande qui m’a été faite est de trouvé une alternative pour le module bluetooth. Celle que j’ai trouvée semble adéquate mais au vue des pin à dispositions sur le microcontrôleur une discussions est nécessaires. Car dans l’idée, il me fallait ajouter les empreintes des 2 modules pour plus tard, choisir lequel monter lors de l’assemblage. Une solution serait de ne pas mettre l’empreinte du module mikroE, uniquement celui du module. Ou ajouter un I/O extander pour piloter les leds de signalisation, et laisser de l’espace directement sur le microcontrôleur


## 3.4 Sortie relais

Pour piloter les relais, un MOS N, avec une résistance série, et une pull-down, pour figer l’état à 0V. et une diode de roue libre 1N4001, car je ne pense pas qu’une Schottky soit nécessaires.


## 3.5 Entrées analogique

Le but du montage permet la lecture d’un capteur 0-10V entre 0 et 3,3V c’est un simple pont diviseur 1/3. Lorsque le commutateur est enclenché la résistance de 500Ω mise en parallèle fixe la tension sur le pont à 10V 10/(0,02)=500 . Ce qui permet de lire la tension une fois encore entre 0 et 3V.


## 3.6 Protection

Les diodes TVS choisies sont celle à disposition dans le stock de l’ES qui nous à été conseiller d’utiliser pour ces projets. Elles ont été placées sur les entrée analogiques, les entrées destinées à d’autres SPB, et sur les entrée « Spéciales » « SPE_IN ».

## 3.7 Switch de configuratio4n

Pour la redirection des signaux sur la sortie de dérangements une série de switch directement reliés à des pull-up / pull-down.


## 3.8 PCB TOUCH_CAPA

Pour le pcb touch capca, il reste simple avec comme exemple le projet n°2123 Démonstrateur de panneau Touch. Les résistances ont été sélectionnées à la valeur minimale recommandée par le datasheet pour apporter le plus de sensibilité possible.


Lausanne, le 09.11.2024

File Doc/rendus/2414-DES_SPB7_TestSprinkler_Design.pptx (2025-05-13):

## Design Présentation

- Par: Clauzel Aymeric

## Sommaire

- Description du produit
- Justifications
- Aspect particuliers
- Détails
- Concept logiciel
- manque

## Description du produit:

- Module d’interfaçage avec un extendeur de système de détection d'incendie
- Contrôleur de boucle de courant
- Contrôle de dispositif externes
- Signalisation visuel et sonore
- Configuration manuelle
- Data logger
- … Mais n’est pas conforme à la norme EN 54-13.

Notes: En gros un contorlleur de boucle de courant extension des capacités dun système de detection incendie exstant
Dispositif ESR
Grace au relais programmable
Switch / touch capa/ résistances externes

norme EN 54-13 detection incedie

## Justification/description:


Uc

Signalisation

Sorties.1

Sorties.2

Alimentation

## Uc / Microcontrôleur


- Assignation des pins
- Position des Bus
  - I2C2
  - UART1
  - LCD
- Découplage
- Pin restantes 1

## UC/Bluetooth


- la


## UC/Modif RTC


## UC/USB→UART

USB2.0
Semi-duplex
Vitesse ?


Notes: 480MB/sec

## Signalisation/BUZZER


U=3,3V

VGS=0,8V
IL =~70mA → ok ?

Cannal N


U=2,5V
I=0,07A
P= 0,175W

## Signalisation/LEDS


R=U/I=(3,3−1,9)/(0,005)=280Ω→E12 270Ω
P=R⋅I^2 =280⋅0,005^2 =0,007w


## Signalisation/LCD graphique


- Transmission série
- I= ~75mA


## Alimentation


… non isolé

## Sortie.1/Relais-out

- Relais de Sortie
- Rechercher d’autres


## Sortie.2/Connecteurs/Touch-capa


- Choix positions alimentations
- BUS

## Sortie.2/Connecteurs/SPBS_IN


- Entrée des différents SPB

## Sortie.2/Connecteurs/Entrée libres


## Sortie.2/Connecteurs/SPECIALS_IN


## Sortie.2/Connecteurs/Essert_IN/OUT


## LE TOUCH CAPA


- Valeurs résitances

## Les concepts du logiciel


## Manque

- Ce que j’ai oublié
- Connecteur pour le LCD
- Temps/Motivation

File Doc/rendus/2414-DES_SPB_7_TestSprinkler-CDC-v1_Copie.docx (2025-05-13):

# Projet ETML-ES - Cahier des charges

DES SPB 7 Test Sprinkler

2124

Entreprise/Client: | DES Sécurité | Département: | Génie électrique
Demandé par (Prénom, Nom): | Edouard Schubert | Date: | 30.10.2024

Auteur (ETML-ES): | - | Filière: | SLO2
| | Date: | jj.mm.2024

# 1 But du projet

Il s’agit de réaliser une évolution d’un boîtier de test pour Sprinkler (détection incendie - DI).

Il faudra répliquer des fonctions de test basées sur l’existant, ajouter des fonctions nouvelles, comme un affichage, des boutons tactiles, de nouvelles entrées analogiques, une mémorisation de données dans un journal daté et un moyen de récupérer ces données.

Le système sera équipé d’un microcontrôleur (MCU) de la famille PIC32 pour lequel on pourra mettre à jour le firmware par une connexion USB.

Le boîtier devra être similaire à celui de version précédente, mais son couvercle sera transparent avec pour but d’éviter tous perçage/usinage pour l’interface utilisateur.

Le livrable principal est un ou plusieurs PCBs avec le dossier de production terminé, qui pourront être produits par la FAB électronique de l’ETML. Ils doivent aussi pouvoir être assemblés par Eurocircuits en Europe.

# 2 Spécifications du projet

## 2.1 Boîtier

Boîtier plastique avec couvercle transparent avec les dimensions s’approchant le plus possible des suivantes :

Longueur : 200 mm

Largeur : 120 mm

Hauteur : 75 mm

Boîtier suggéré : PN-1334-C de Bud Industries

## 2.2 Cartes électroniques

SPB7 : PCBA principal dans le boîtier du SPB (boîtier de contrôle sprinkler). C’est le 1er PCB à développer dans ce projet. Il peut potentiellement être décomposé en 2 PCBs, dont un comportera des touches capacitives.

SAG13 : Petit PCB de test de ligne, qui s’intercale entre le SPB7 et une ligne d’alarme ou surveillance. C’est le 2e PCB à développer.

4in -2out: carte fournie (Esserbus Transponder), interface avec système détection incendie (DI), elle doit pouvoir s’enficher sur le SPB7 pour faciliter les tests.

SPB6 : PCBA de la version existante.

## 2.3 Généralités

Le nouveau SPB7 aura les caractéristiques suivantes :

1. Grande robustesse dans les locaux humides
2. Le couvercle transparent du boîtier est fixé sur la base au moyen de 4 vis. Un tournevis type cruciforme est le seul outil nécessaire pour accéder à l’intérieur du boîtier.
3. Un joint entre les 2 parties du boîtier assure la résistance à l’humidité du SPB7.
4. Le PCB sera équipé de bornes à enficher pour fils de 0.8 mm. (sur SPB6, ces bornes sont à vis)
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

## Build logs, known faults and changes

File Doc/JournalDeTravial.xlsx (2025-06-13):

Hrs/date | voir commit altium
12:15:00 | etude des documents + compréhention de la demande
 | 2024-11-22
 | compréhension des documents et modification du cahier des chargesetude du projet 2123 problèmes pour maintient du module et emcombrement mécanique
 | 2024-11-29
 | choix de certain composants en accord avec cdc, rencontre mr schubert+ recherche suite composants+ études des normes en rigeure lors de design de detection incendie
 | 2024-12-06
 | rédaction pré-étude, visuel solidworks estimation encombrement pour touch capa
 | 2024-12-13
 | présentation- changement microcontrlleur, contact sec - en gros ta rien capter personne ta aider et personne t'aidera alors bon change - ragequit
 | 2024-12-20
 | création des documents schéma sur altium changement d'avis pour le buzzer -> siren
 | 2025-01-10
 | schéma voir commit altium
 | 2025-01-17
 | schéma voir commit altium
 | 2025-01-24
 | schéma voir commit altium
 | 2025-01-31
 | schéma voir commit altium
 | 2025-02-07
 | PCB voir commit altium
 | 2025-02-14
 | PCB voir commit altium
 | 2025-02-28
 | PCB voir commit altium
 | 2025-03-07
 | PCB voir commit altium
 | 2025-03-14
 | PCB voir commit altium
 | 2025-03-21
 | PCB voir commit altium
 | 2025-03-28
 | PCB voir commit altium
 | 2025-04-04
 | PCB voir commit altium
 | 2025-04-11
 | PCB voir commit altium
 | 2025-05-02
 | soft voir commit git
 | 2025-05-09
 | soft voir commit git
 | 2025-05-16
 | soft voir commit git
 | 2025-05-23
 | soft voir commit git
 | 2025-06-06
 | Assembly creation voir commit git
 | 2025-06-13
 | 2025-08-15
 | 2025-08-22
 | 2025-08-29
 | 2025-09-05
 | 2025-09-12
 | 2025-09-19
 | 2025-09-26
 | 2025-10-03
 | 2025-10-10
 | 2025-10-17

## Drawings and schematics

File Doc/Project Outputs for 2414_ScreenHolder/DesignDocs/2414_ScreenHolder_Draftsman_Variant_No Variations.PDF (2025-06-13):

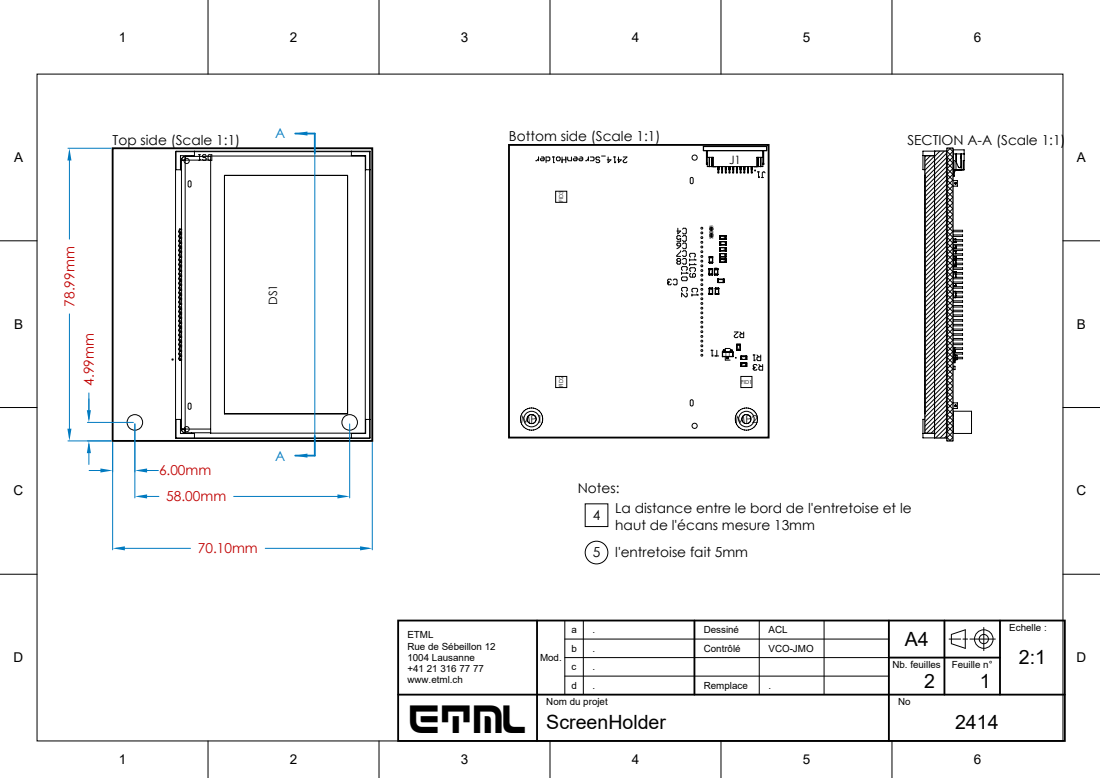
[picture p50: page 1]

Notes:
La distance entre le bord de l'entretoise et le
haut de l'écans mesure 13mm
5 l'entretoise fait 5mm

ETML Rue de Sébeillon 12 1004 Lausanne +41 21 316 77 77 www.etml.ch | Mod. | a | . | Dessiné | ACL | A4 | | Echelle : 2:1

b | . | Contrôlé | VCO-JMO
c | . | | | Nb. feuilles 2 | Feuille n° 1
d | . | Remplace | .

ETML | Nom du projet ScreenHolder | | | | | No 2414

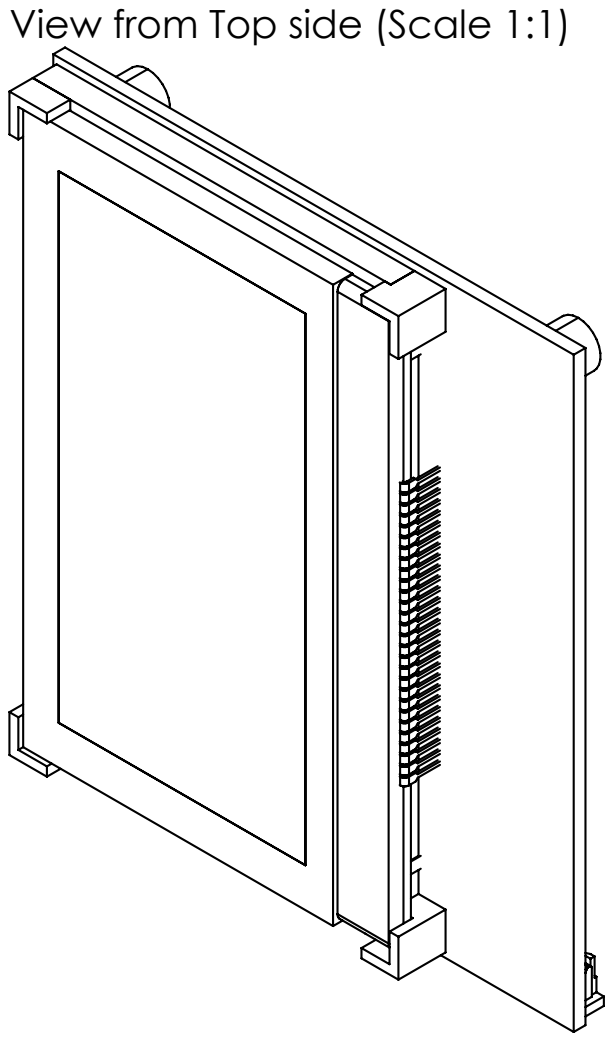
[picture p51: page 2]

View from Top side (Scale 1:1)

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

b | . | Contrôlé | VCO-JMO
c | . | | | Nb. feuilles 2 | Feuille n° 2
d | . | Remplace | .

ETML | Nom du projet ScreenHolder | | | | | No 2414

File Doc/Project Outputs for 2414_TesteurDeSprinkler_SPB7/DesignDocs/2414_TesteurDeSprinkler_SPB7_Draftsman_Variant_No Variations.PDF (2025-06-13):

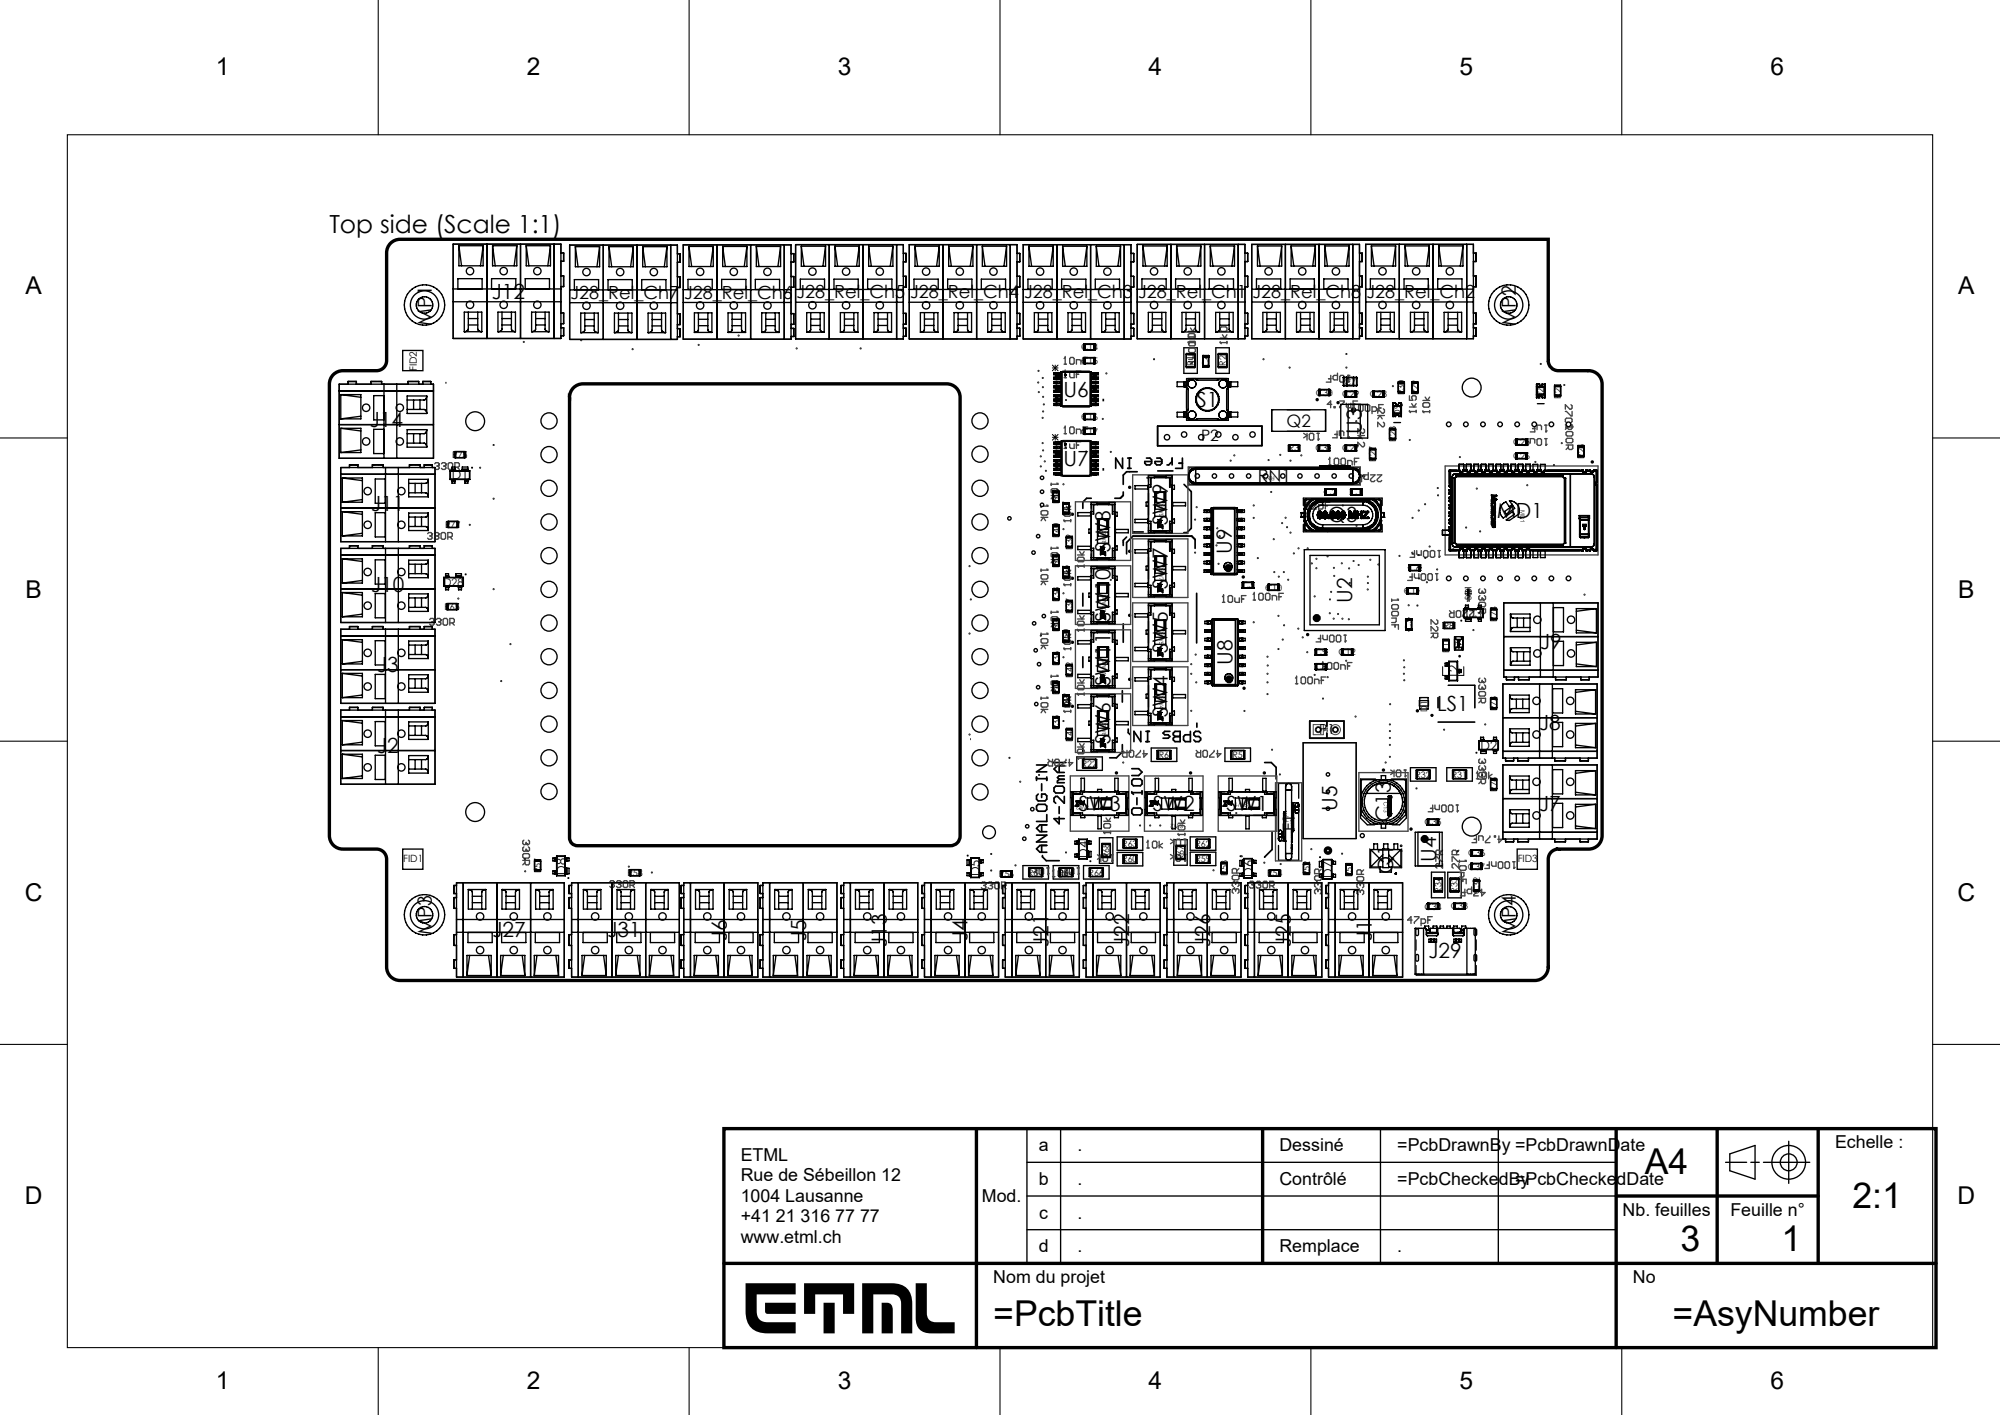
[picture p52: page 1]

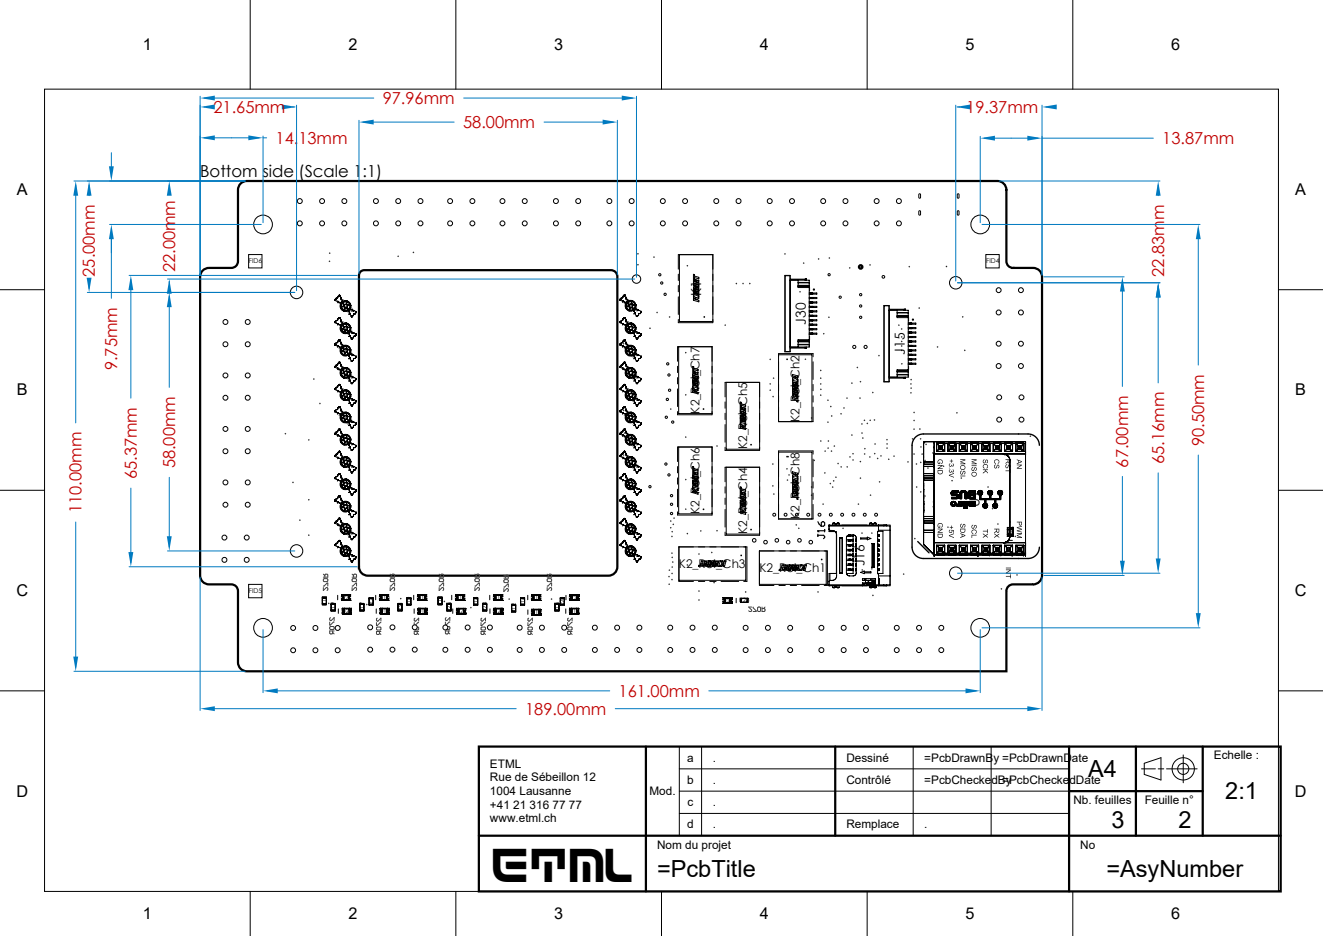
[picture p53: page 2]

ETML Rue de Sébeillon 12 1004 Lausanne +41 21 316 77 77 www.etml.ch | Mod. | a | . | Dessiné | =PcbDrawnBy | =PcbDrawnDate | A4 | | Echelle : 2:1

b | . | Contrôlé | =PcbCheckedBy | =PcbCheckedDate
c | . | | | | Nb. feuilles 3 | Feuille n° 2
d | . | Remplace | .

ETML | Nom du projet | | | | | | No

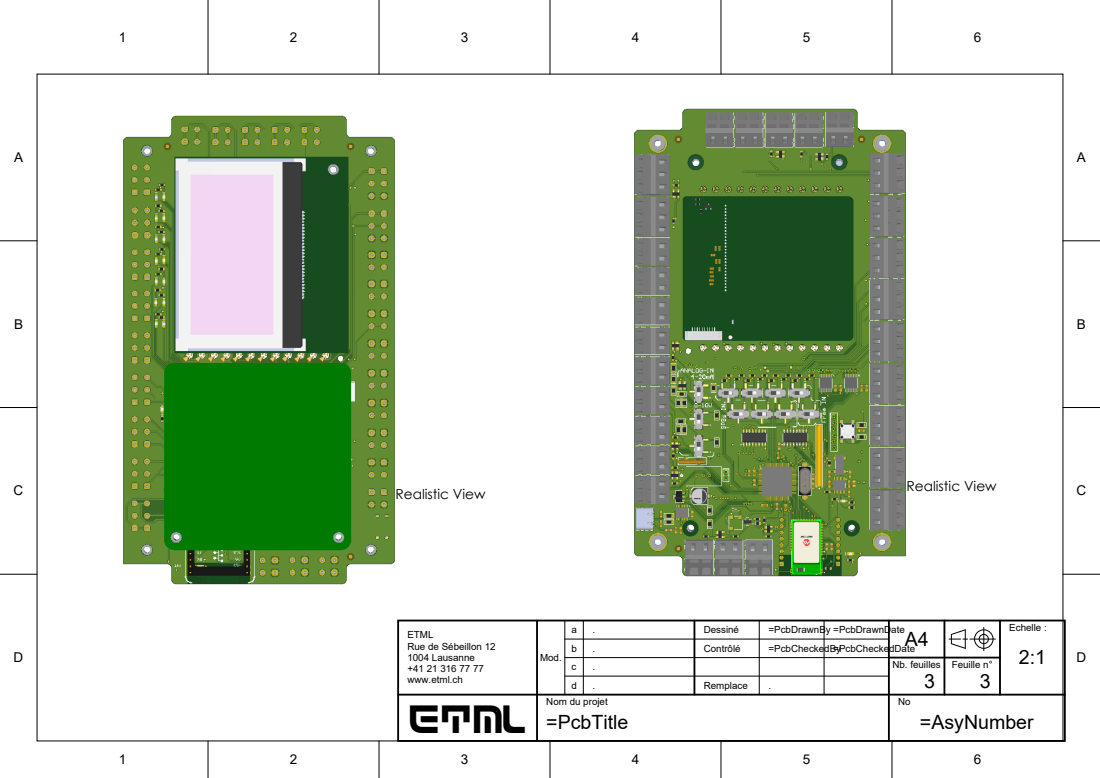
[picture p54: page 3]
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

b | . | Contrôlé | =PcbCheckedBy | =PcbCheckedDate
c | . | | | | Nb. feuilles 3 | Feuille n° 3
d | . | Remplace | .

ETML | Nom du projet | | | | | | No

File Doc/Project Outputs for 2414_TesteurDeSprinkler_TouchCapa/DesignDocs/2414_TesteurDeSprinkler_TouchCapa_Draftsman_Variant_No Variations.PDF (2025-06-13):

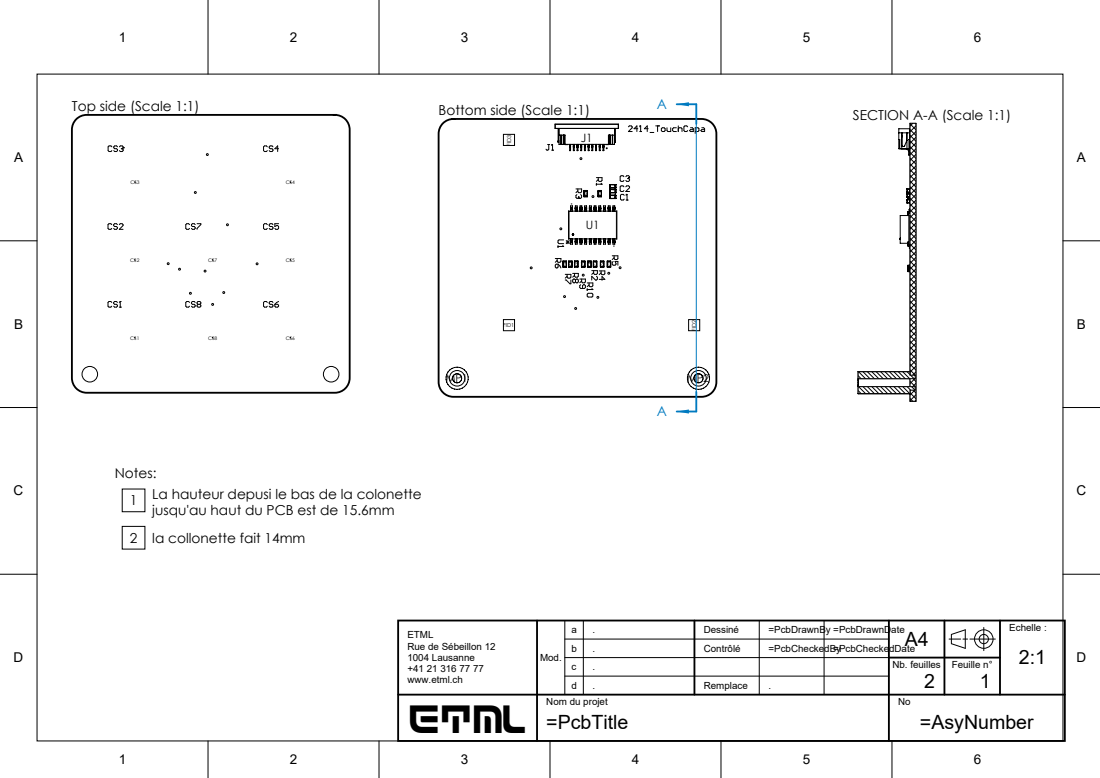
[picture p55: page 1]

Notes:
La hauteur depusi le bas de la colonette
jusqu'au haut du PCB est de 15.6mm

ETML Rue de Sébeillon 12 1004 Lausanne +41 21 316 77 77 www.etml.ch | Mod. | a | . | Dessiné | =PcbDrawnBy | =PcbDrawnDate | A4 | | Echelle : 2:1

b | . | Contrôlé | =PcbCheckedBy | =PcbCheckedDate
c | . | | | | Nb. feuilles 2 | Feuille n° 1
d | . | Remplace | .

ETML | Nom du projet =PcbTitle | | | | | | No =AsyNumber

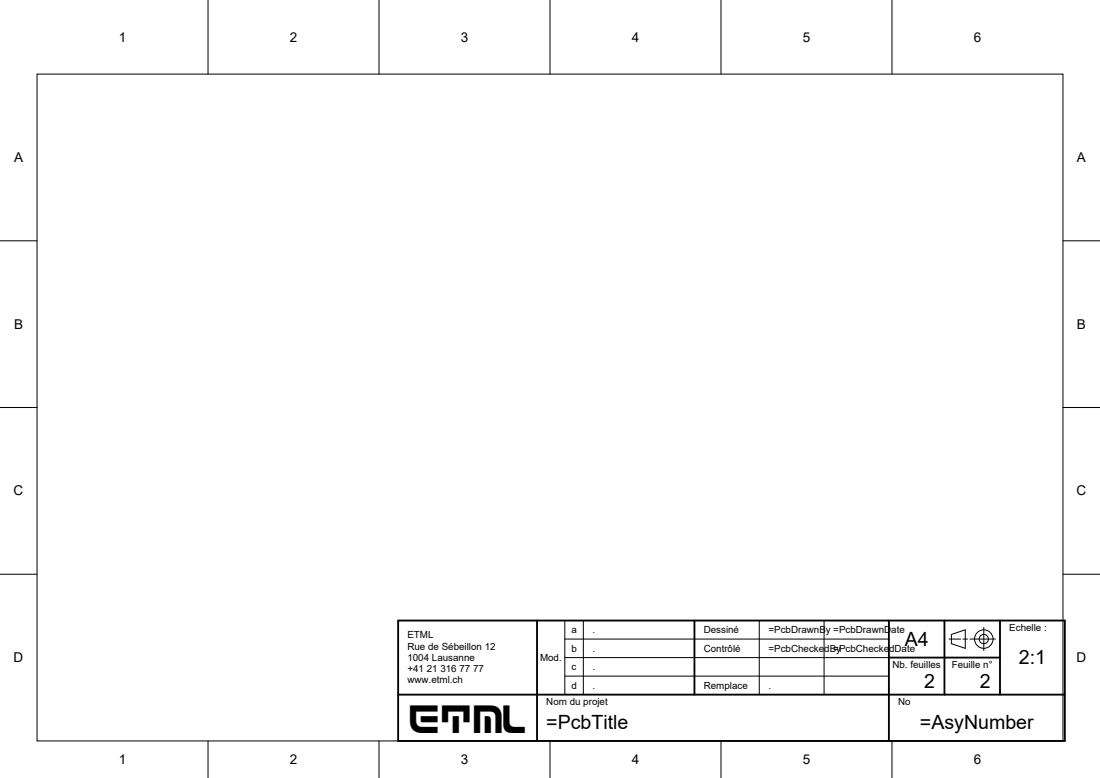
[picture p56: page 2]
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

b | . | Contrôlé | =PcbCheckedBy | =PcbCheckedDate
c | . | | | | Nb. feuilles 2 | Feuille n° 2
d | . | Remplace | .

ETML | Nom du projet =PcbTitle | | | | | | No =AsyNumber

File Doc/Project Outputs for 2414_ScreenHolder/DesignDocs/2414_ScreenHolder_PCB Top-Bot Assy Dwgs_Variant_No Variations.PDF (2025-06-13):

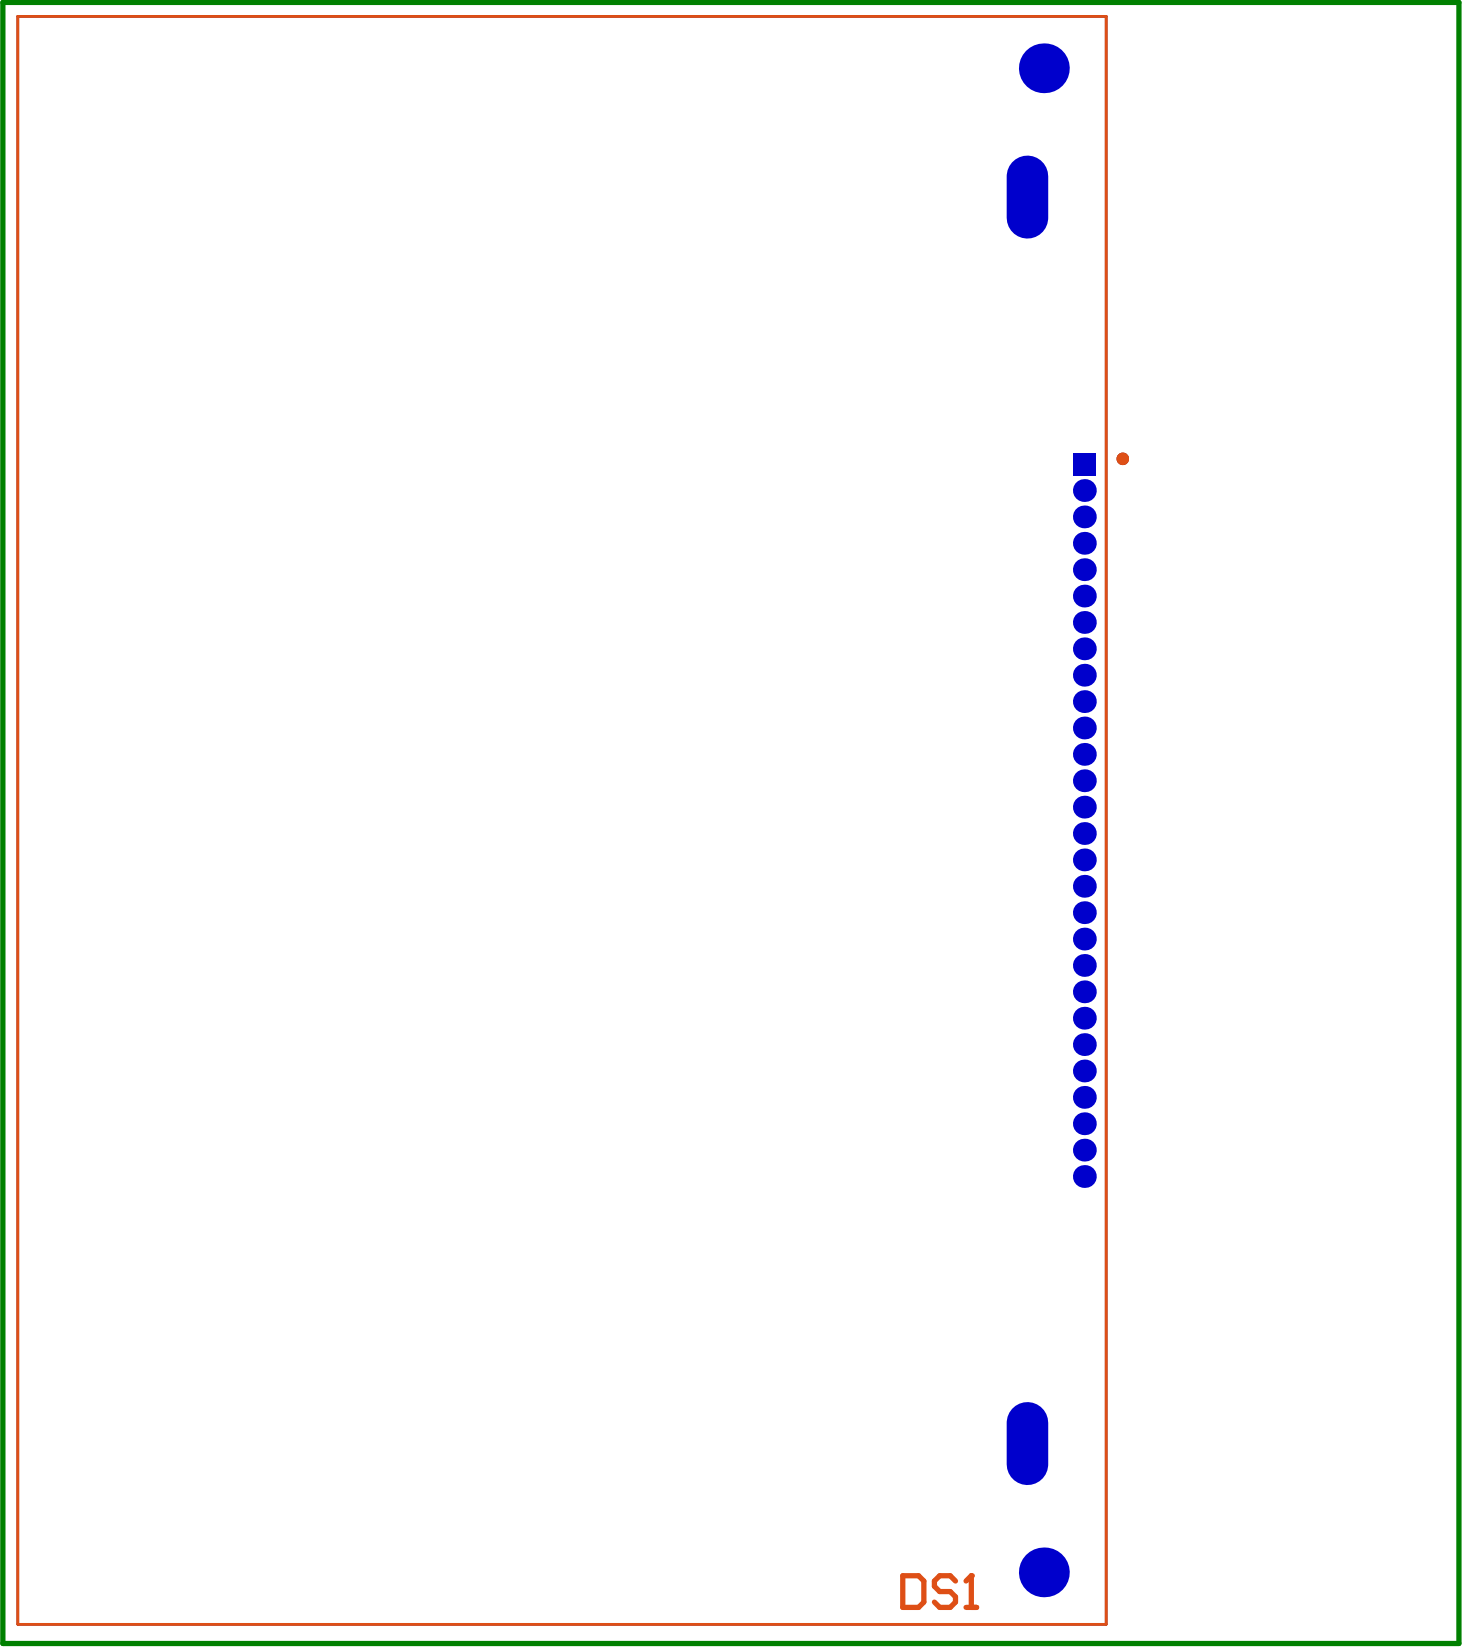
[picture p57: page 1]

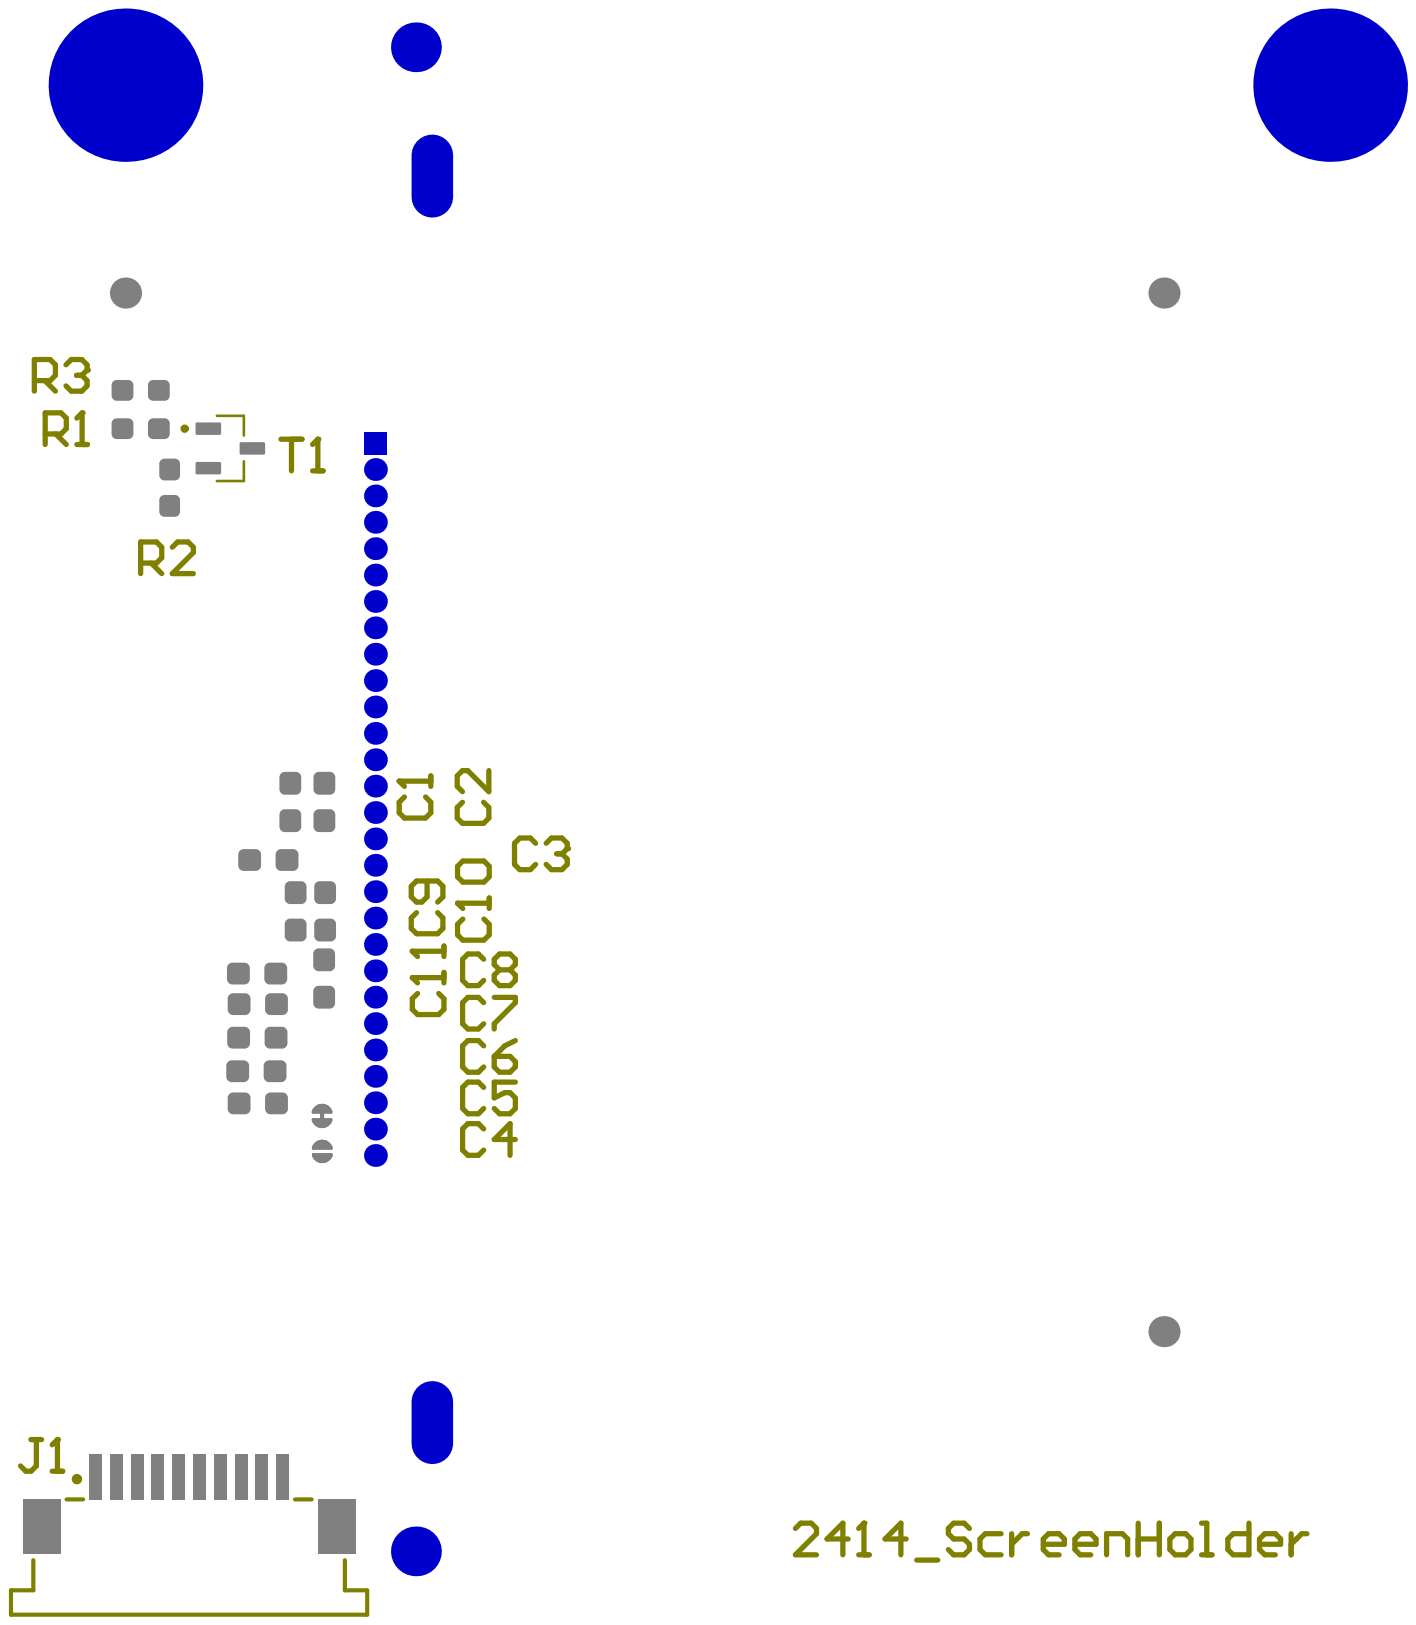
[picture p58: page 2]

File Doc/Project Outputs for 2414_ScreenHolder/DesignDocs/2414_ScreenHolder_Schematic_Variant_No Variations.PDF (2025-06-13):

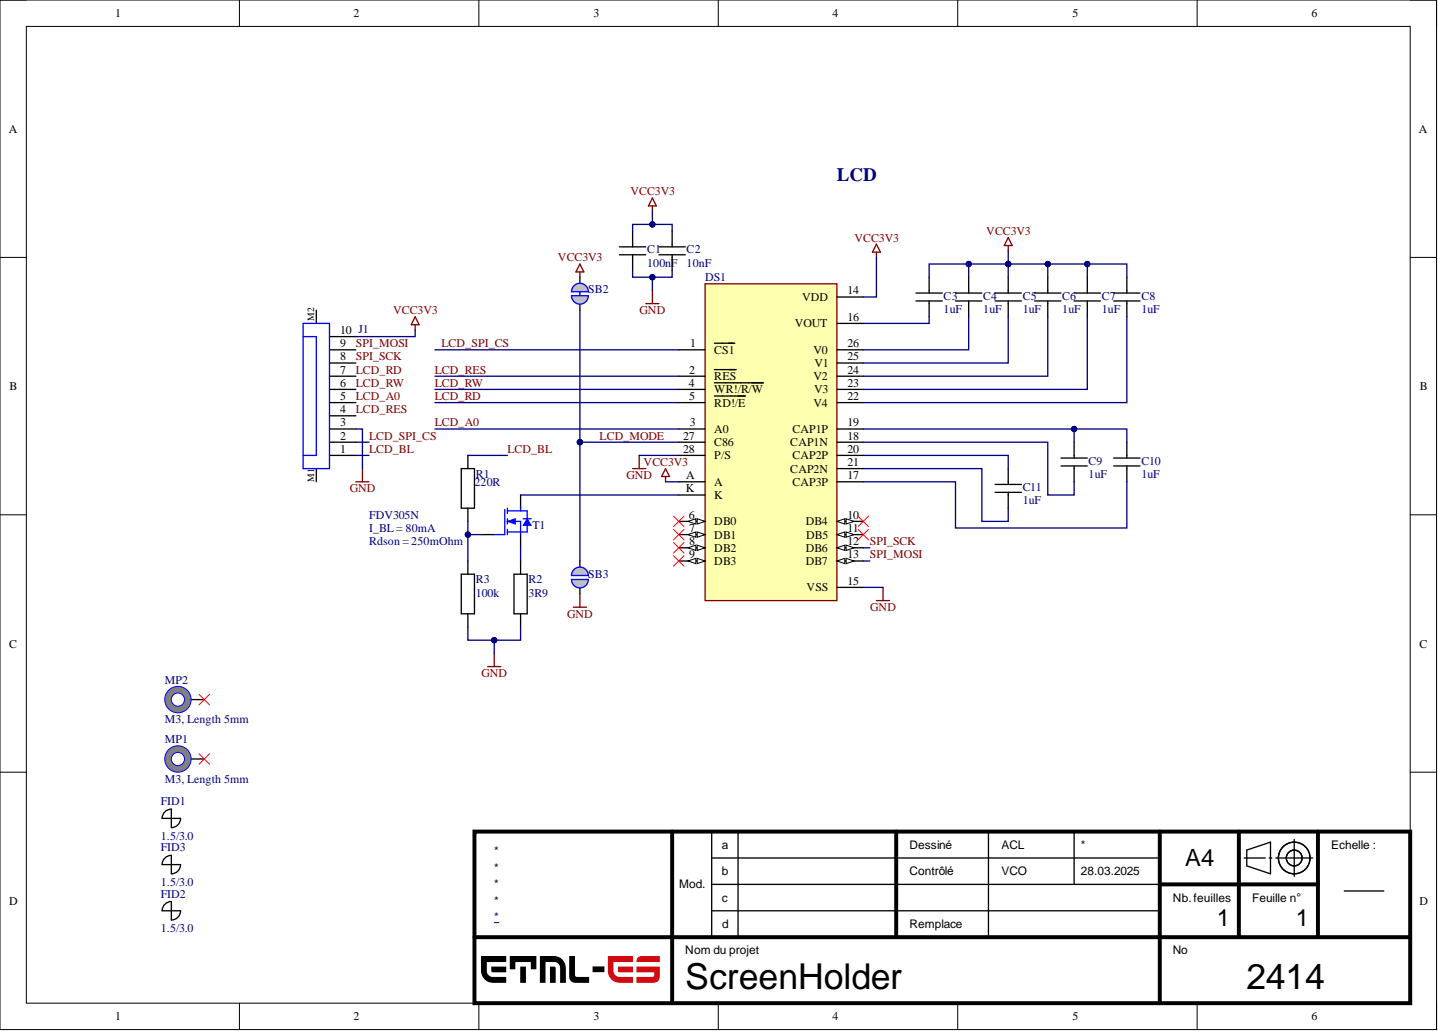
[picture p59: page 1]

2 8 G | 2 0
N D A K | 2 1

1 7
1 0 | C1 1

** *** | Mod . | | Des s i n é | AC L | * | A4 | | Echelle :

abcd | Cont r ô l é | VC O | 28.03.20 2 5

Nb. feuilles 1 | Feuille n ° 1

Rempla c e

Nom du projet ScreenHol d e r | | N o 241 4

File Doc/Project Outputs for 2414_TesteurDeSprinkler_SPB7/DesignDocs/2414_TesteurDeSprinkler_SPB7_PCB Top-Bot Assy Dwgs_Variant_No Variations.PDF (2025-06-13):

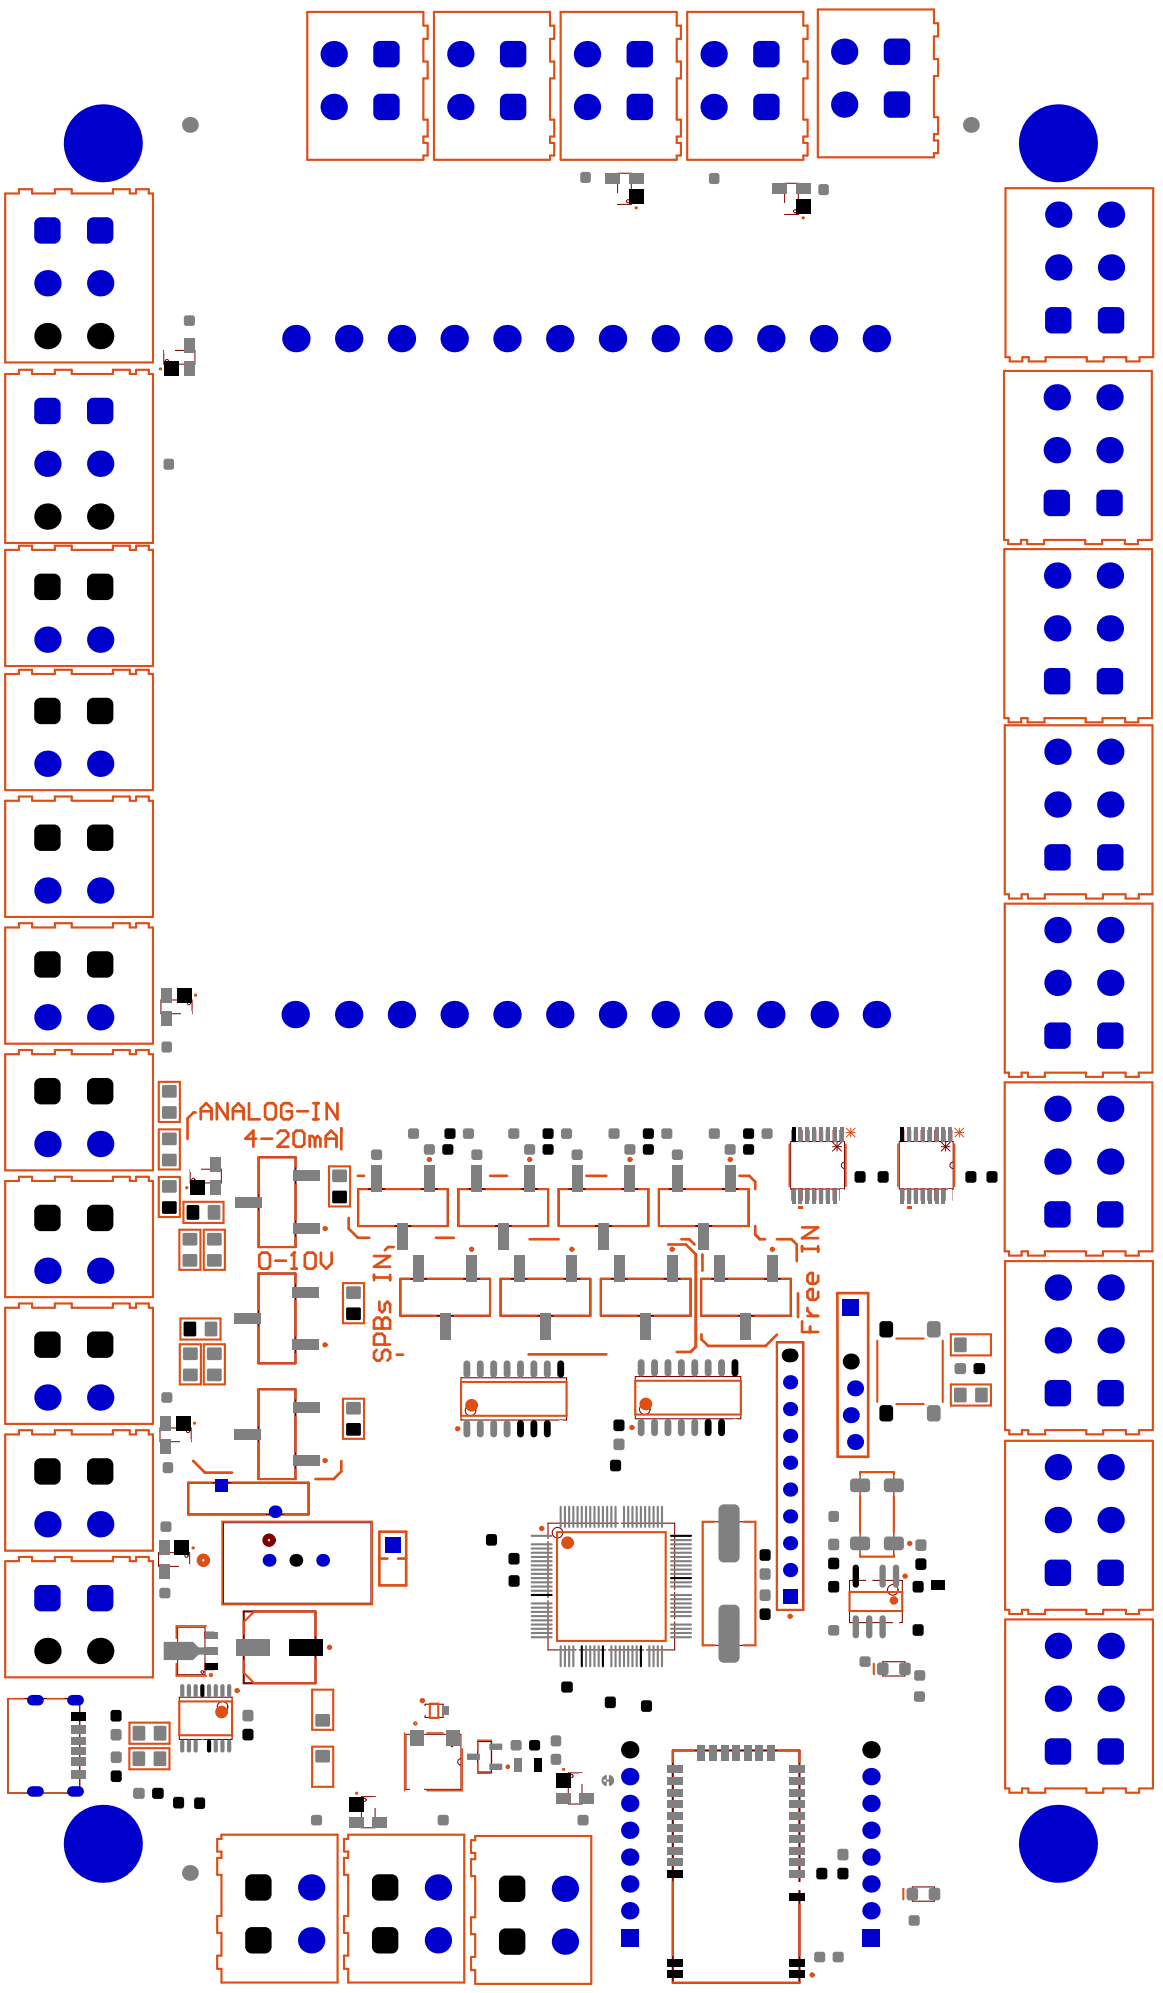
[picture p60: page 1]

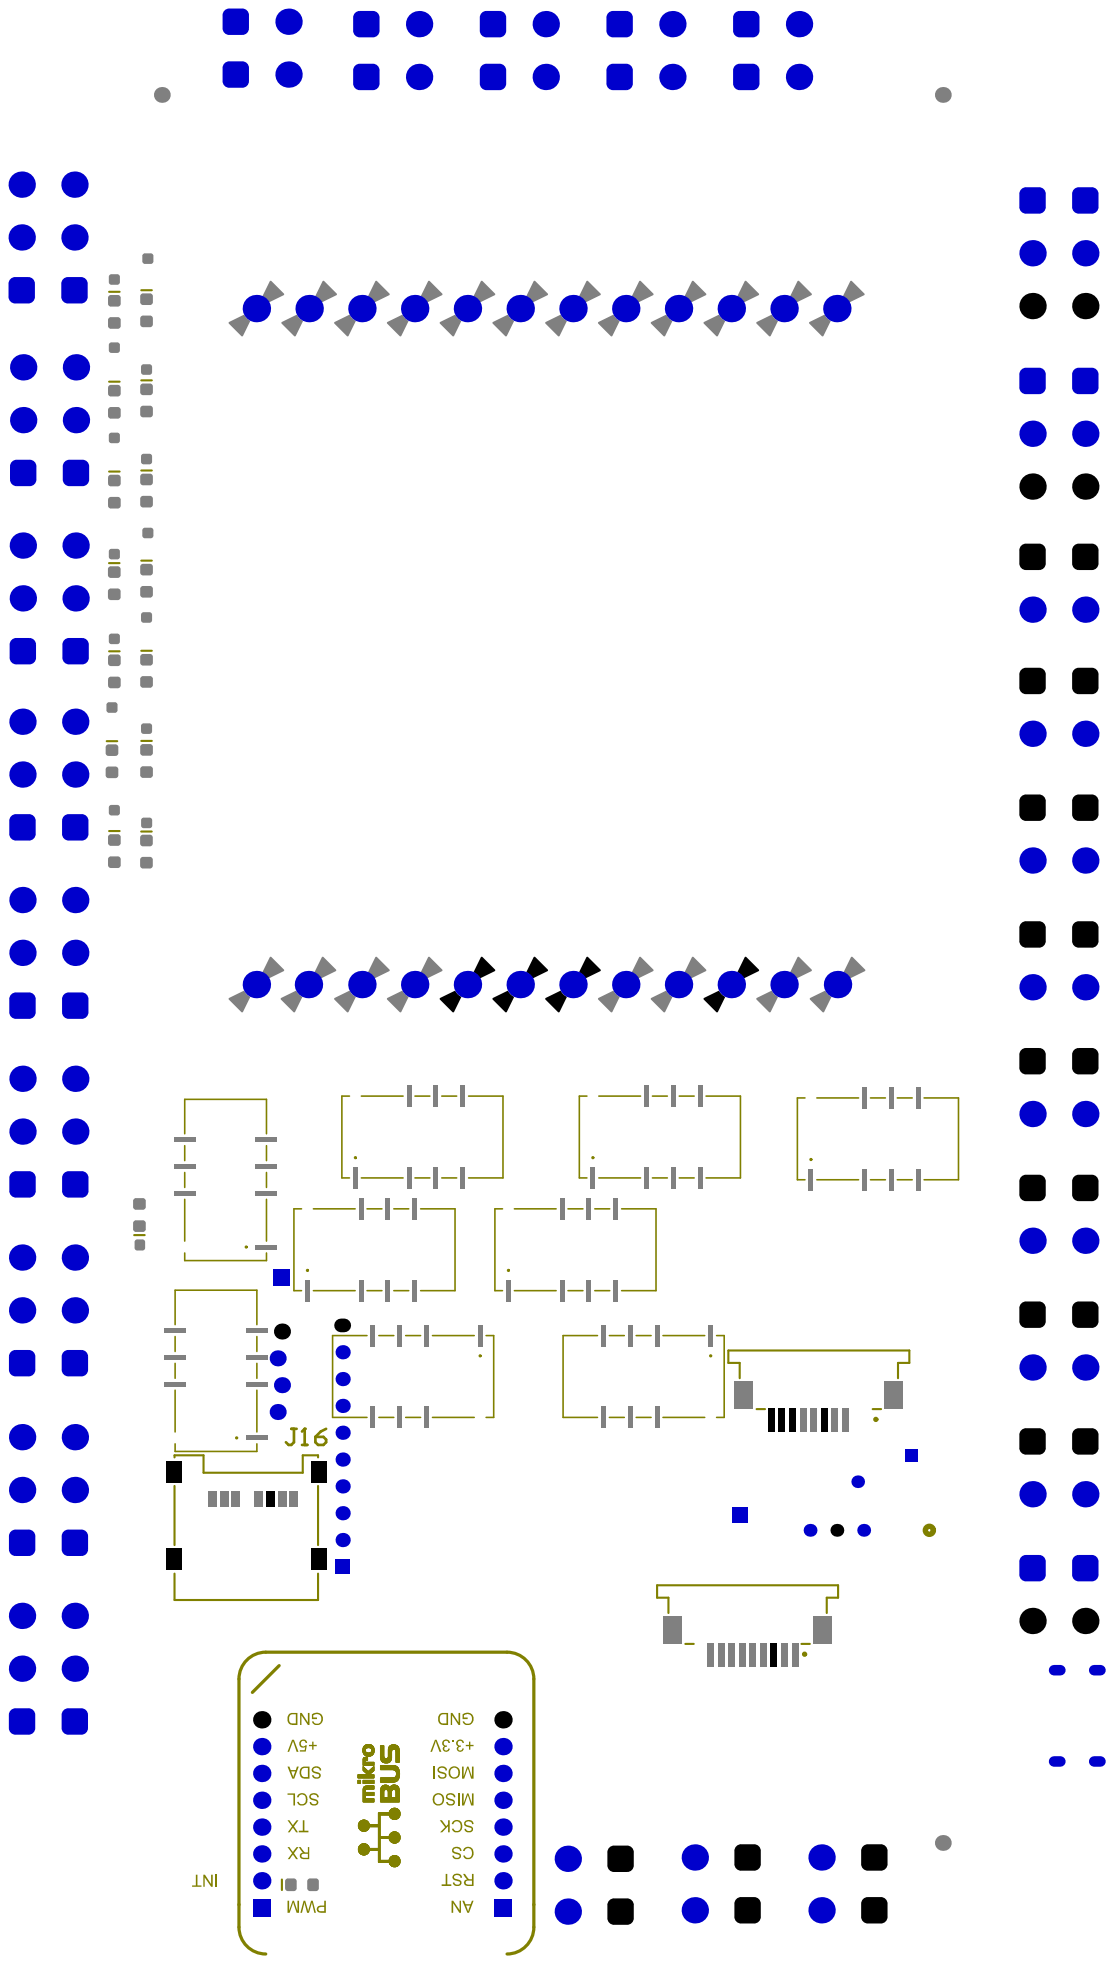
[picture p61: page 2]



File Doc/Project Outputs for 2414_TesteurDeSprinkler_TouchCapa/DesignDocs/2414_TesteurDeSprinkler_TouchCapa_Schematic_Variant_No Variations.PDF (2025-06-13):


Condo a mettre au plus proche du capteur

* * * * * | Mod. | a | Dessiné | ACL | * | A4 | | Echelle :

b | Contrôlé | VCO

c | | | | Nb. feuilles 1 | Feuille n° 1

d | Remplace

Nom du projet TouchCapa | | | | | No 2414

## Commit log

2025-05-23 removing PCB from cached need to exclude them from versionning
    [21-0487_T822CN+1_ADI.step, 21-0487_T822CN1_ADI.step, 2414-SAG13.PcbDoc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]
2025-05-23 add gitignore
    excluding PCB need to see AD365
2025-06-13 no time
    [2414_TesteurDeSprinklerplanif.xlsx, JournalDeTravial.xlsx, PN-1334_Copie.SLDASM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]
2025-06-13 for work on school pc
    [2414_SAG.xlsx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]
2025-06-13 ajout des sofft pour rendu
    [21-0487_T822CN+1_ADI.step, 21-0487_T822CN1_ADI.step, 2414-SAG13.PcbDoc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]
2025-06-13 last push
    [2414-SAG13.PcbDoc, 2414-SAG13.PrjPcb, 2414-SAG13.SchDoc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]
2025-06-16 la ?
2025-06-19 chore: correcting bom
    [2414_TesteurDeSprinkler_SPB7.xlsx]
